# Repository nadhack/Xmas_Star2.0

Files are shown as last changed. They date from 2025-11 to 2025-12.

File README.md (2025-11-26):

Design files and documentation for the NADHack Xmas Star V2.0 as used in 
the SMD soldering workshop 2025.

* Addons - Addon files, source  and reference designs to enhance your stars.
* Docs - Assembly documentation greated using [MkDocs](https://www.mkdocs.org/)
* Hardware - [KiCad](https://www.kicad.org/) design files.

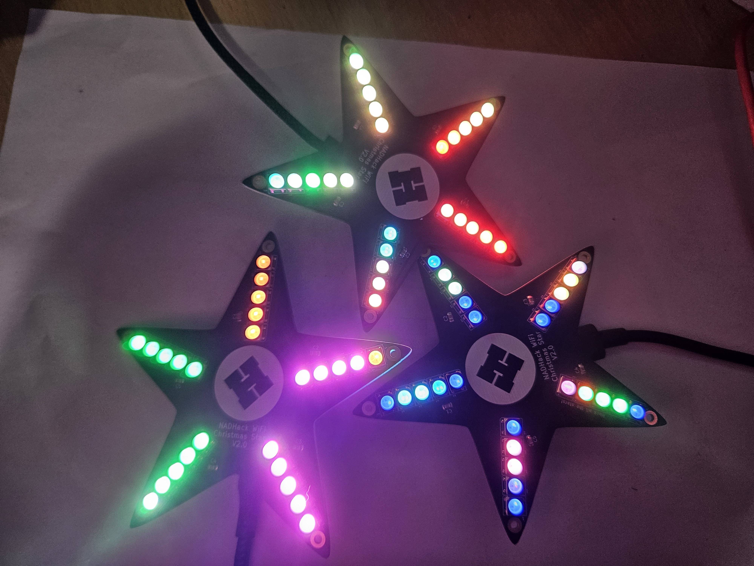
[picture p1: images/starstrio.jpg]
Trio of stars


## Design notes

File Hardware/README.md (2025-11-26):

Hardware files for the NADHack Xmas Star V2.0.

* ESP32_Xmas_Star_Module - [KiCad](https://www.kicad.org/) design files.
* Jigs - Source and 3D print files for holding star PCB while applying solderpaste.

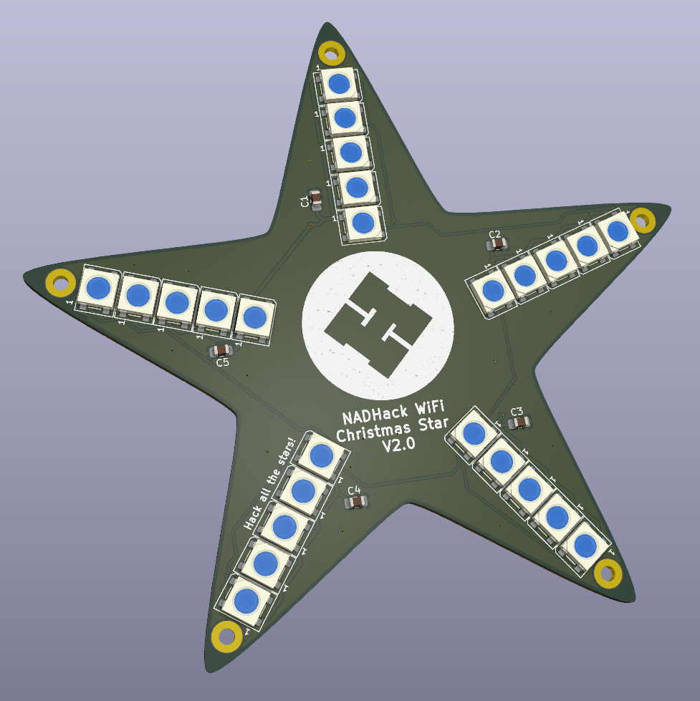
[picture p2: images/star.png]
rear


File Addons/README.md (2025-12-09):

Addon files for the NADHack Xmas Star V2.0.

These can be used as a starting point for your own projects. Source and usable files are available.

The main file is *staroutline.svg* which was used to create the star PCB outline. This can be used to get the correct shape.

Other files:

* *StarCover* Diffuser cover for star created with [OpenSCAD](https://openscad.org/). Source file and *.stl* file suitable for 3D printing.
* *StarBracket* Bracket for star, example is a tree topper created with [OpenSCAD](https://openscad.org/). Source file and *.stl* file suitable for 3D printing.
* *Seasonal_Star* for those that want a desk stand, Fusion360 and *.stl* file suitable for 3D printing. Designed and kindly shared by Craig Hogan.

Star cover/diffuser
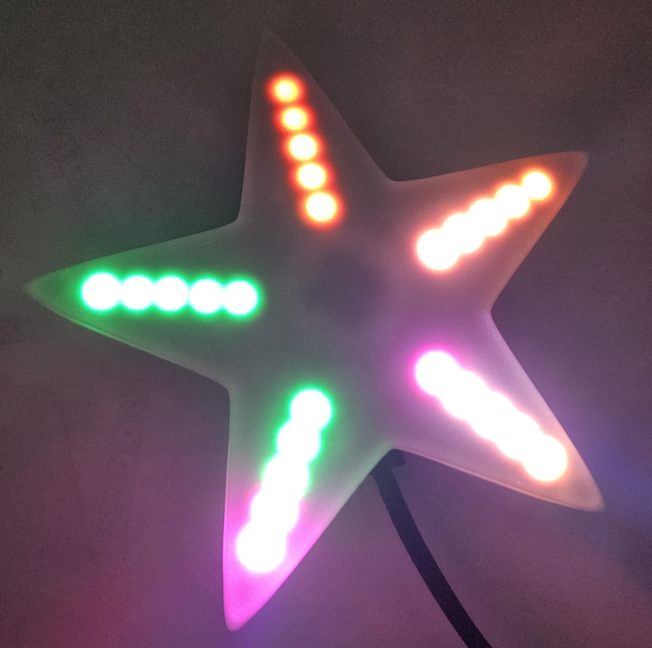
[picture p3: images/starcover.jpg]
starcover


Tree Topper bracket
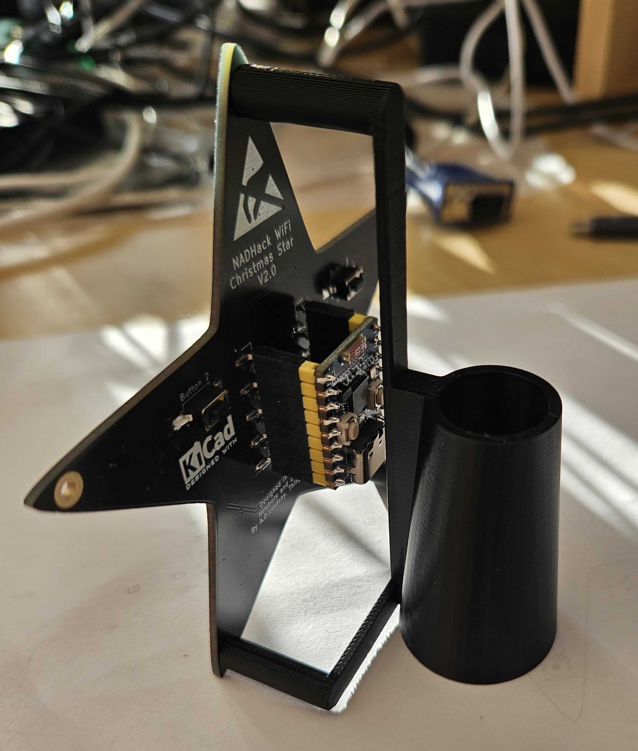
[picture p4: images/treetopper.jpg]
treetopper


Star Stick - Designed and kindly shared by Craig Hogan

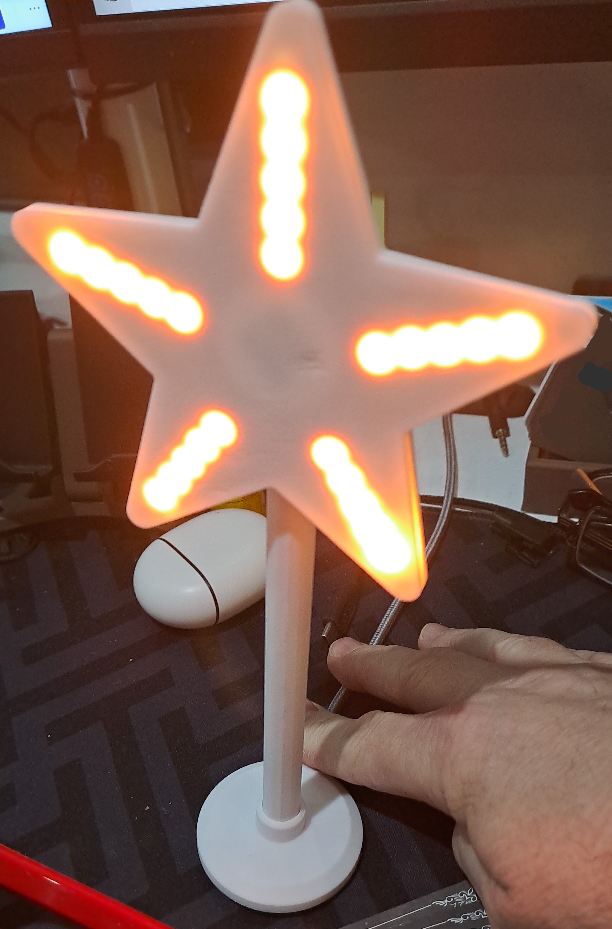
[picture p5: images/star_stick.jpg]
starstick


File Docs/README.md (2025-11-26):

Assembly documentation created using [MkDoc](https://www.mkdocs.org/)

Folders:

* docs - the source files
* site - the built files for uploading to a webserver. Currently viewable at [https://star.thingdevices.uk](https://star.thingdevices.uk)

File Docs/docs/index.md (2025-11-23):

# NADHack Introduction to Surface Mount Soldering workshop 2025

Welcome to the NADHack Introduction to Surface Mount Soldering workshop 2025!

Workshop aims:

* Show you the basic process for assembling a project using SMD components
* You try the process yourself to assemble a project
* Take home a working fully programmable, addressable LED star based on the ESP32-C3 Zero module.

# The NADHack Xmas Star V2.0

Has the following features:

* ESP32-C3 module with WiFi and Bluetooth.
* 25 individually addressable RGB LEDs.
* Programmable using Arduino IDE or can use ready made firmware such as WLED, which we will use.
* WLED includes an App to controll the star.
* Cool star shape with mounting and hanging holes.

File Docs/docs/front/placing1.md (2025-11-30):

# Front component Placement

The components should be identified, 5 capacitors and 25 addressable LEDs.

Working on one point of the star at a time, arrange 5 LEDs in the correct order, noting the position of the triangular cutout. This indicates pin 3, not the usual pin 1. Each point is placed identically.
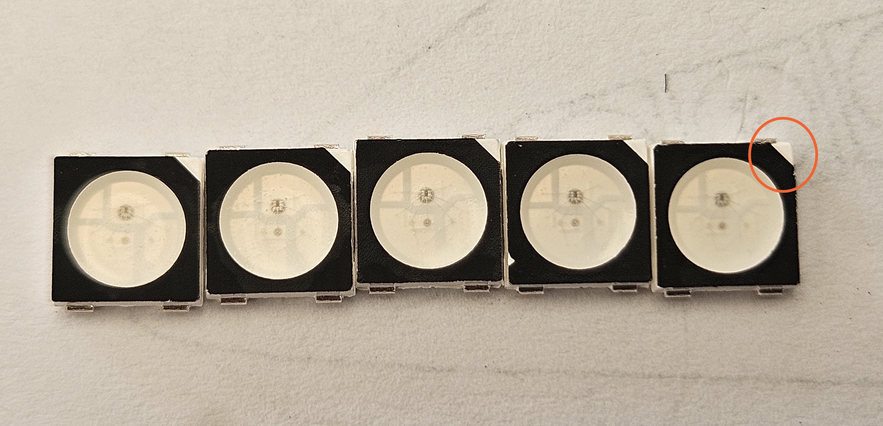
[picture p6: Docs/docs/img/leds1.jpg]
Placing LEDs


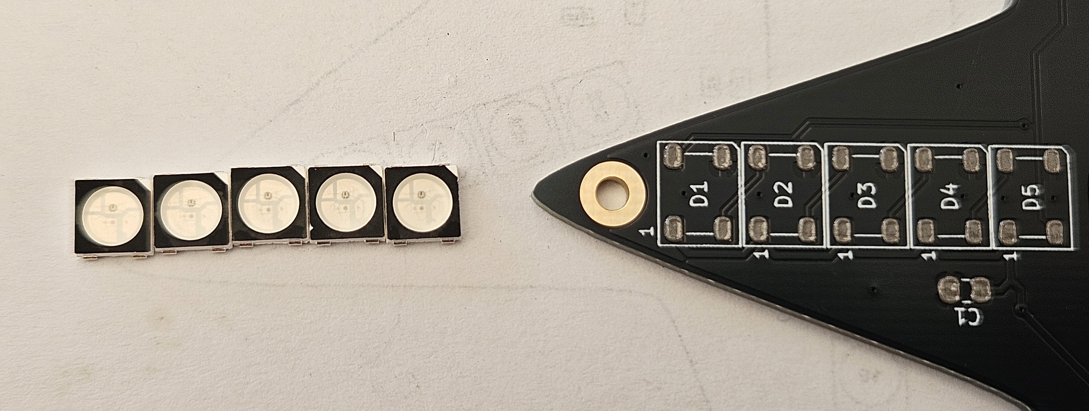
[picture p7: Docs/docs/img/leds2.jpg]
Placing LEDs


Using tweezers, place one of the capacitors onto the pads, use a coctail stick to hold the component down while removing the tweezers just incase it sticks and lifts away.
Place the first LED on the pads closest to the centre of the star, taking care not to have any clothing, jewellery or body parts touch the rest of the PCB as this could rub away the solderpaste. 
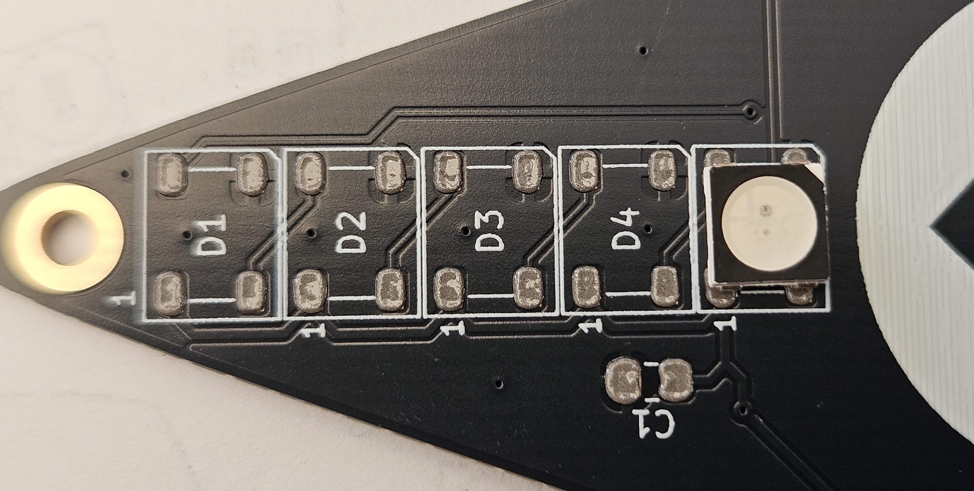
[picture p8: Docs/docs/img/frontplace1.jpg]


Line up 5 LEDs, orientated correctly and place one at a time on each star point.
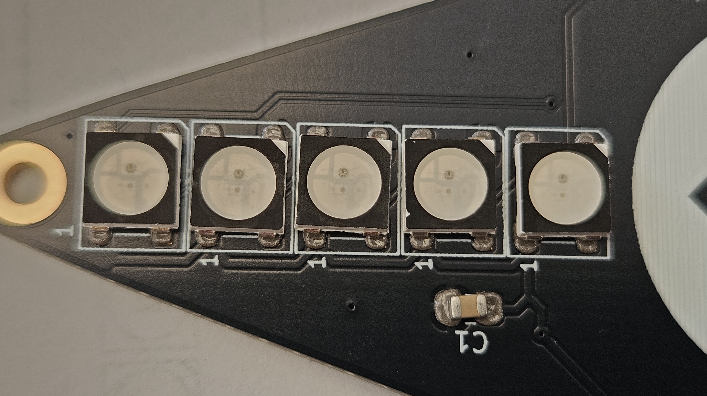
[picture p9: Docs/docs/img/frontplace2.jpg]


The board should look like this
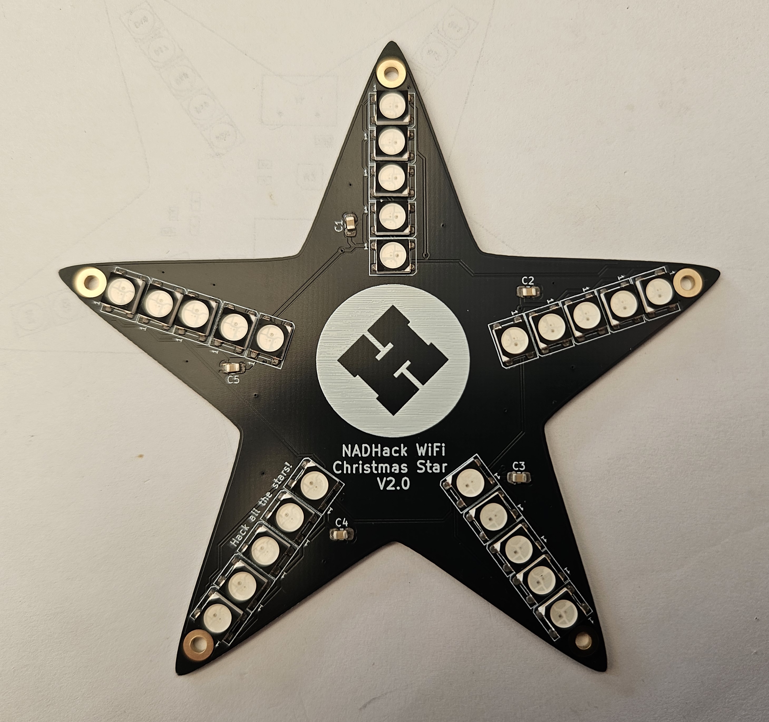
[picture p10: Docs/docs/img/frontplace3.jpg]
End result


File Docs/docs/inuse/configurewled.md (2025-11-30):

# Configuring WLED

On the ESD bag containing the ESP32 module there is a label with the Access Point (AP) configured on this ESP32 module. Look for the *WLED-AP-xxxxxx* access point using your phone or laptop WiFi and connect to it. The screenshots below are from using a phone to configure the star.
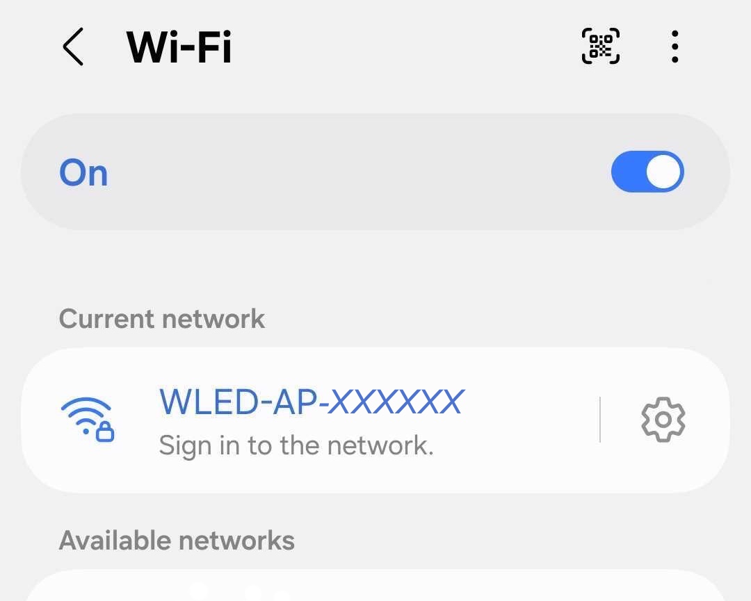
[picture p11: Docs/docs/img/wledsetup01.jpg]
Setup


Click on the correct *WLED-AP-xxxxxx* to connect to it then click on *Sign in to the network* which takes you to the ESP32 WLED configuration. If a password is required then enter *wled1234*.
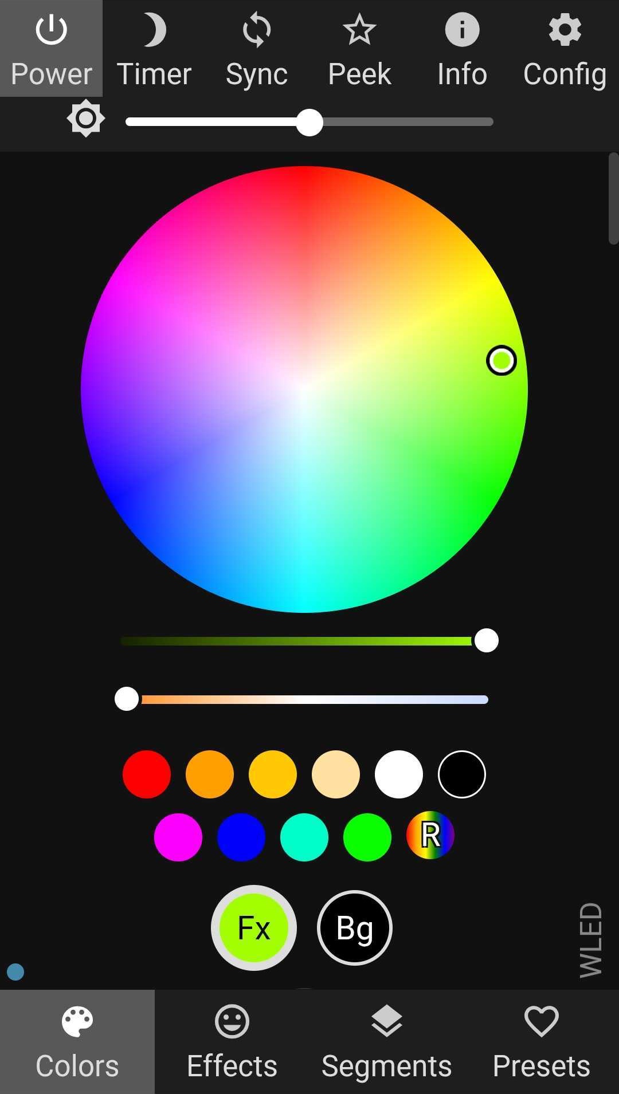
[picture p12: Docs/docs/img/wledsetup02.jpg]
Setup


Click on the *Config* button then the *WiFi Setup* button.
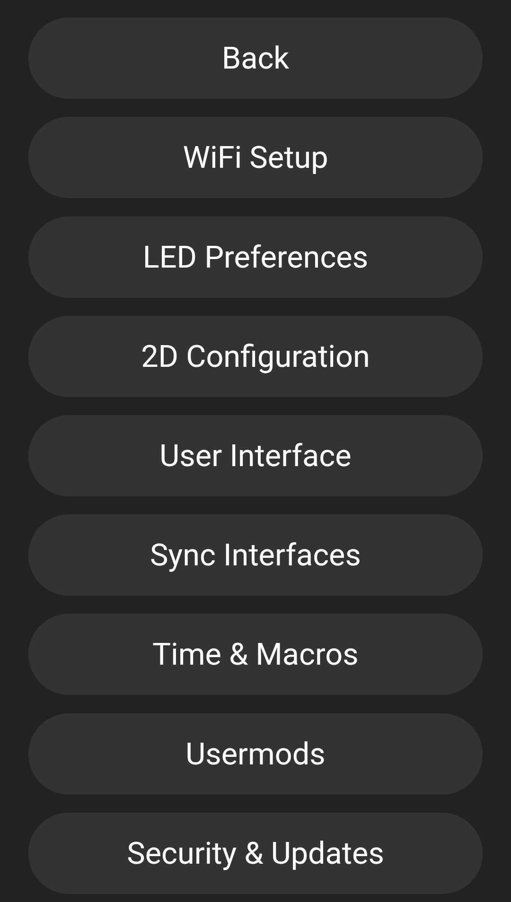
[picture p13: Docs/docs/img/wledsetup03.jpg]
Setup


Enter your WiFi network settings.
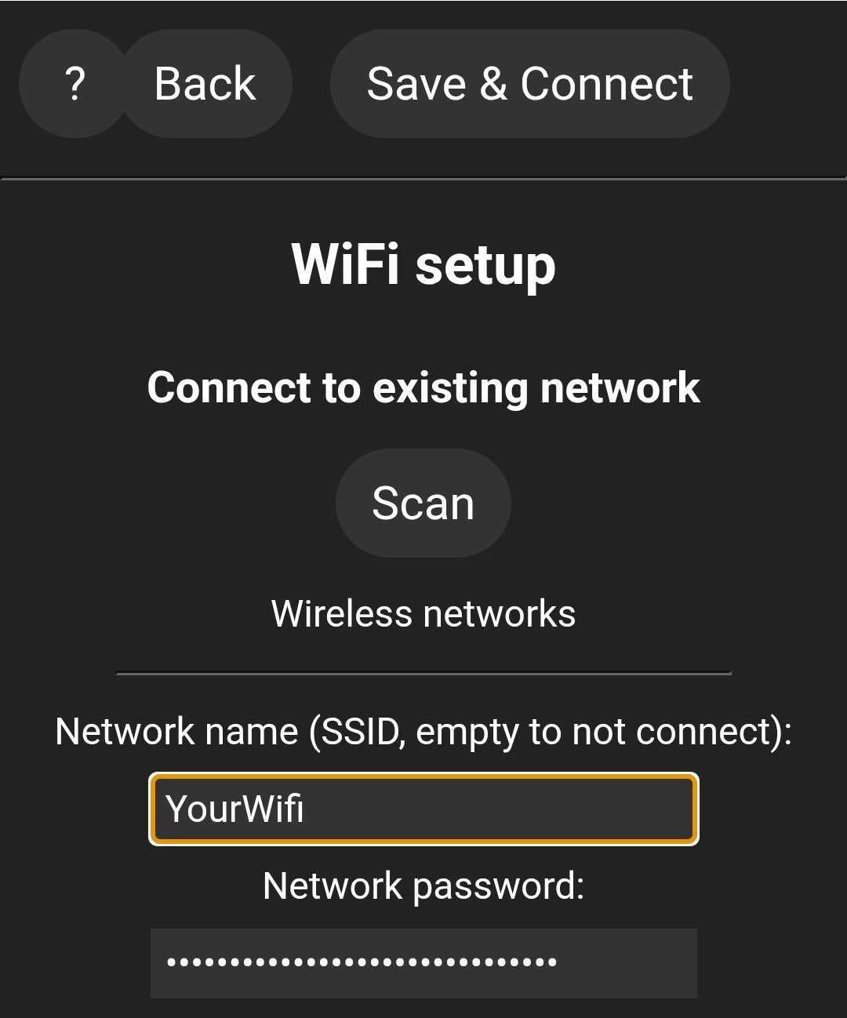
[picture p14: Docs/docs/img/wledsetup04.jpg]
Setup


The app will disconnnect from the star and reconnect to your previously connected WiFi.

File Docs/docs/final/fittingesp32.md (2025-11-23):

# Installing the ESP32 module

Insert the ESP32 module into the header sockets, ensure the USB-C socket is at the correct end, pointing downwards towards the text USB-C.

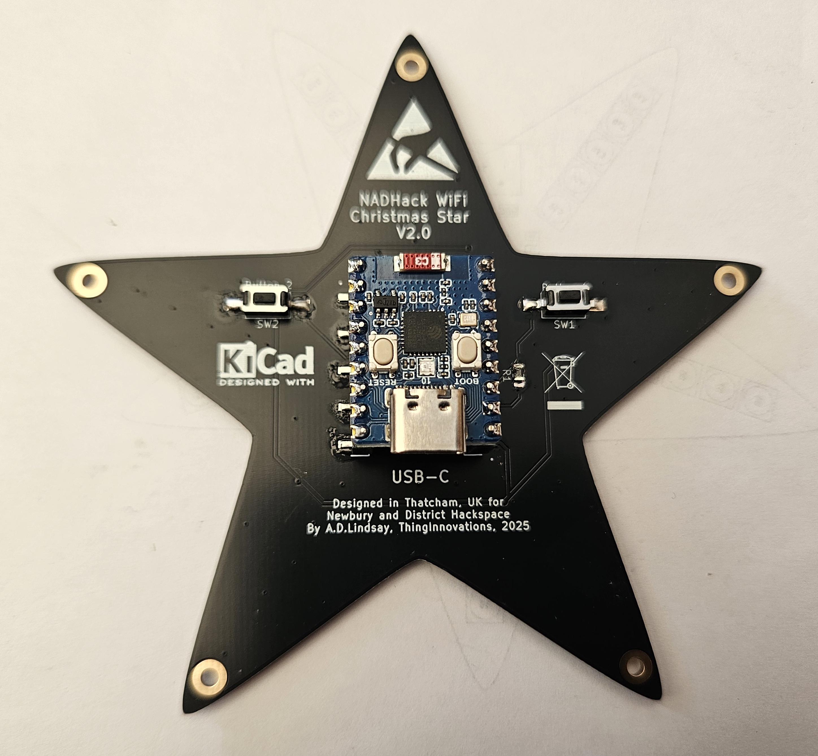
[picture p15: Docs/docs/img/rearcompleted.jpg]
Install ESP32


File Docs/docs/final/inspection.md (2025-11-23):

# Inspection

Before installing the ESP32 module, visually check the solder joints on both the front and rear of the PCB.

Look for:

* Solder bridges between pads.
* Pads not soldered properly.

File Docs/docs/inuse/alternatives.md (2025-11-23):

# Alternatives

As an alternative to using WLED, the ESP32 on the star can be programmed directly using the Arduino IDE. The scope for this is beyond the contents of this workshop.

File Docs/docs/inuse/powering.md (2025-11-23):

# Powering Star

The Xmas Star 2.0 includes a USB-C connector for programming and power. This can be connected to a laptop, USB mains adaptor or a powerbank.

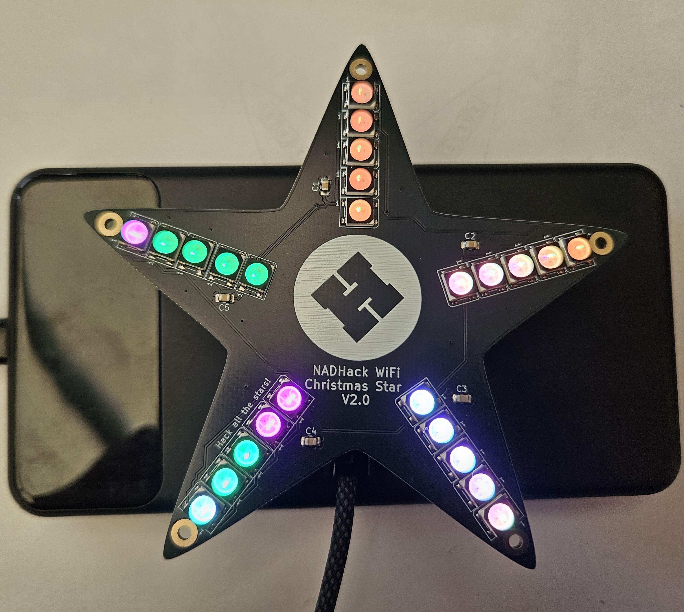
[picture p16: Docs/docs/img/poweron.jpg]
Powering


If you see all the LEDs light up and produce a pattern then congratulations, you have completed the hard part of the workshop.

If your star fails to power up and show a pattern, don't worry, there may be a faulty solder joint. One of the helpers will be able to help and fix it for you.

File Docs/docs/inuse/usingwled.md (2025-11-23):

# Using WLED

Run the *WLED App* and your star should show up. The slider controls the brightnes and the toggle powers the LEDs on and off. Click on the name to enter the configuration screens.
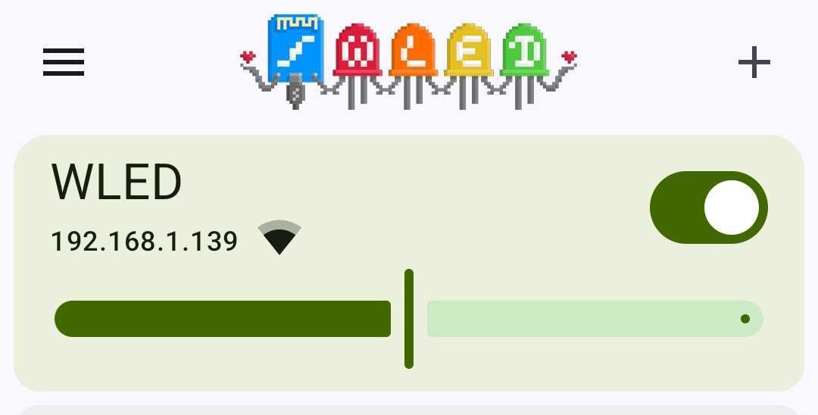
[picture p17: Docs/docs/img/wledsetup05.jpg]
Setup


From the *Config* button, select *LED Preferences* to verify the correct LED setup. It should be set to *WS281x*, Length of *25* and the GPIO set to *2* as shown here.
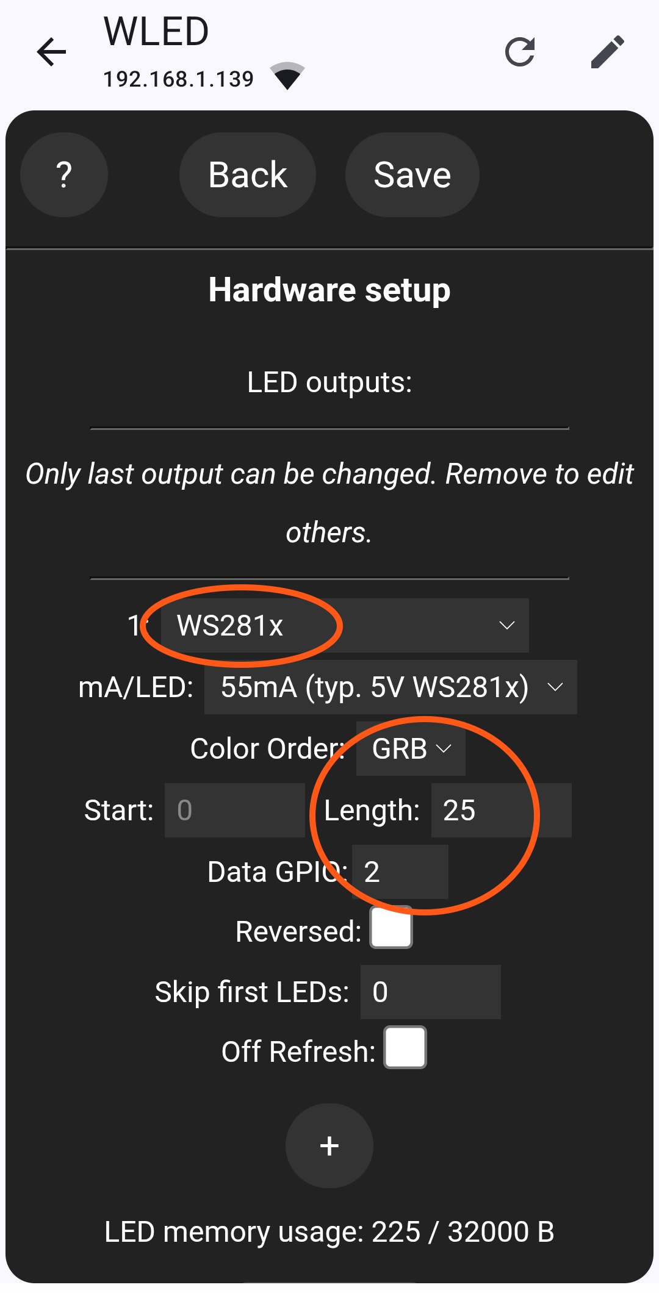
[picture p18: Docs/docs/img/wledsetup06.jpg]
Setup


Selecting the *Effects* button at the bottom brings up a list of effects that can be selected. Some work well with the star, others are more suited to other LED configurations such as LED matrix. 
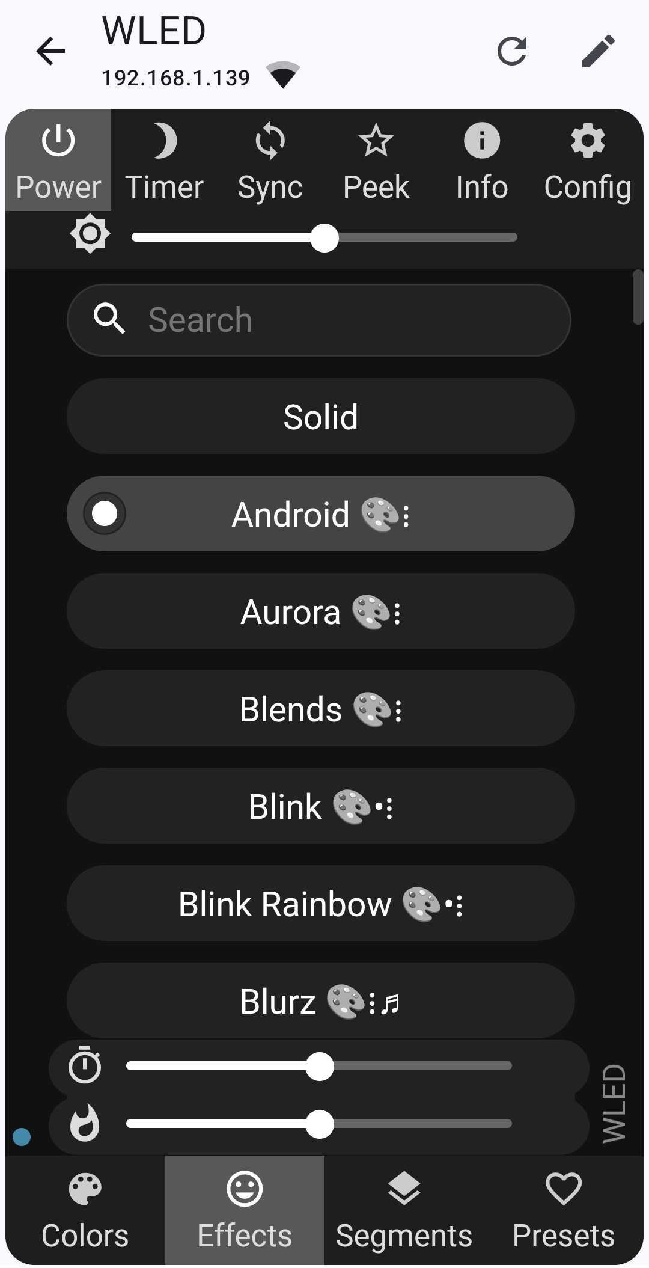
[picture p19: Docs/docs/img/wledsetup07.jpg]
Setup


Selecting the *Colors* (US Spelling!!) button takes to toy a screen where different colour sets can be selected. 
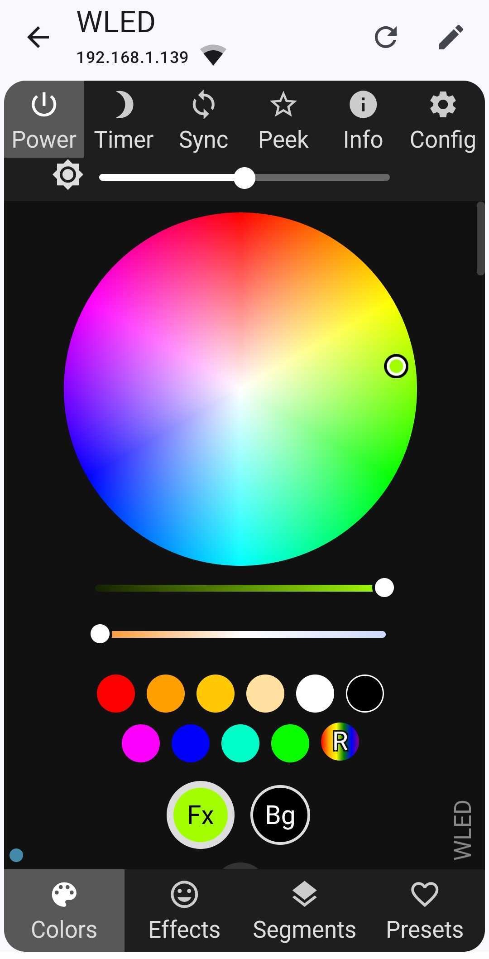
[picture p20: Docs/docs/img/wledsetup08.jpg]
Setup


Once you are happy with an effect and want to keep it, select the *Presets* button at the bottom. If you select the *Apply at boot* then the effect will be shown when your star is powered on without having to use the app to set the colours and effect.
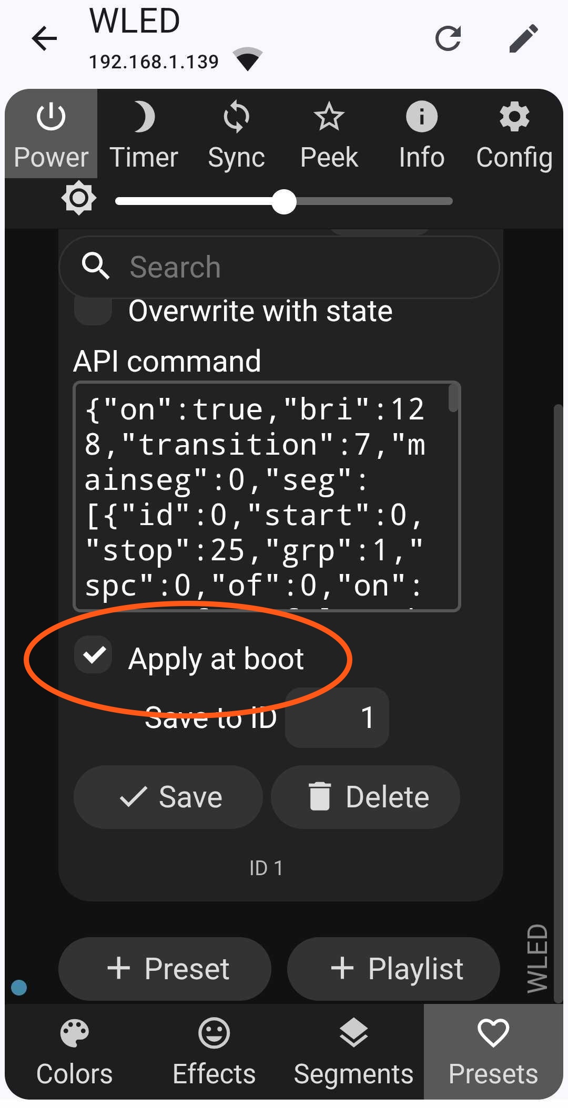
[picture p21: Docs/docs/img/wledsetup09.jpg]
Setup


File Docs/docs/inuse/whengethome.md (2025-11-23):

# When you get home

The first thing to do is to reset the WiFi settings to reconfigure it for your own WiFi.

With the star powered on, hold down the right hand button labelled *SW1* then press and release the *RESET* button. Keep pressing *SW1* for about 10 seconds.

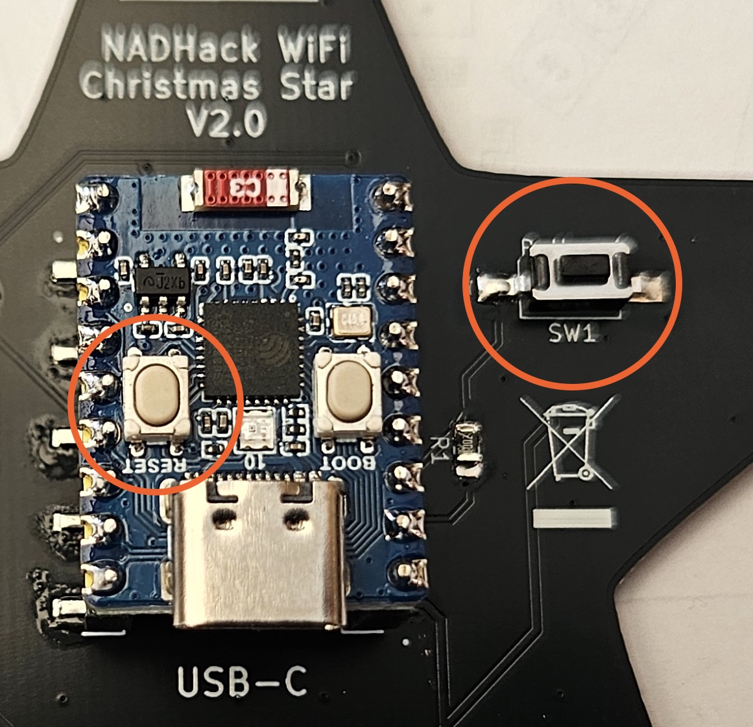
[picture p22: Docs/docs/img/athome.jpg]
reset


Proceed to the previous [setup instructions](configurewled.md)

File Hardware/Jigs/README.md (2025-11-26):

Hardware files for the NADHack Xmas Star V2.0.

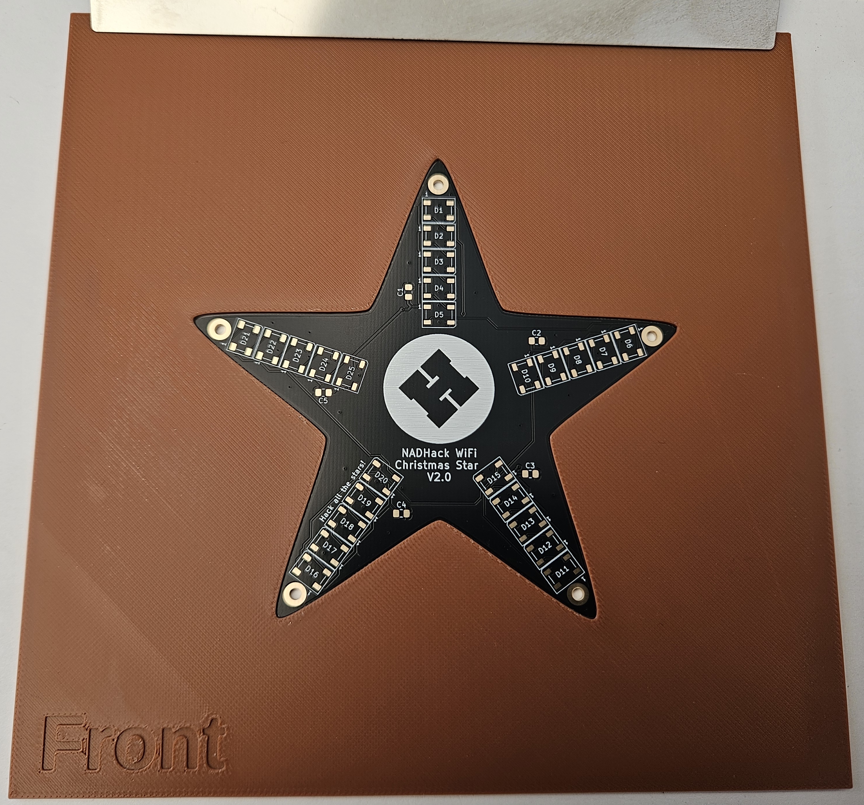
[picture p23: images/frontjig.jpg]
front


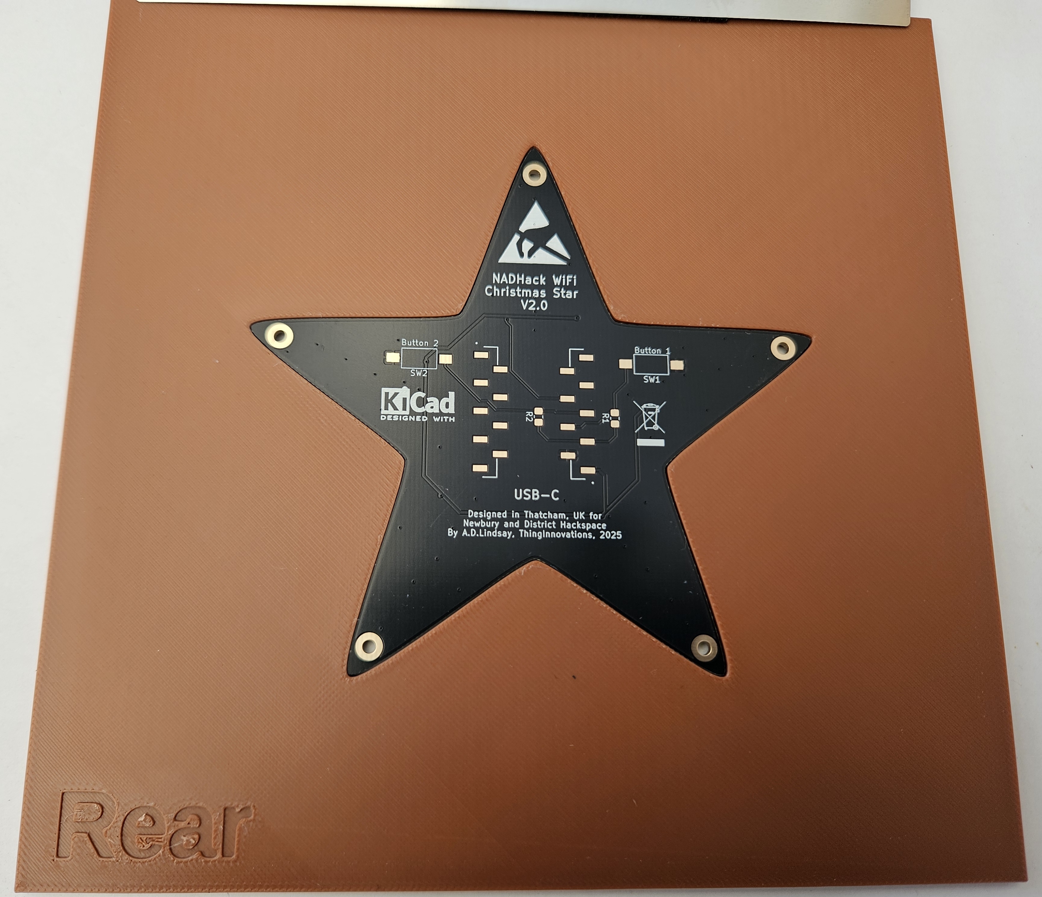
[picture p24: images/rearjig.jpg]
rear


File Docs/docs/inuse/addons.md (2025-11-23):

# Addons

The Xmas Star 2.0 files are all available on the [Github repository](https://github.com/nadhack/Xmas_Star2.0).

The idea is that you have the files you need to create your own addons and new versions. The original star shape outline is available in the file *staroutline.svg*

# 3D printed cover

A simple star shaped diffusing cover created using [OpenSCAD](https://openscad.org/), the script uses the *staroutline.svg* file.
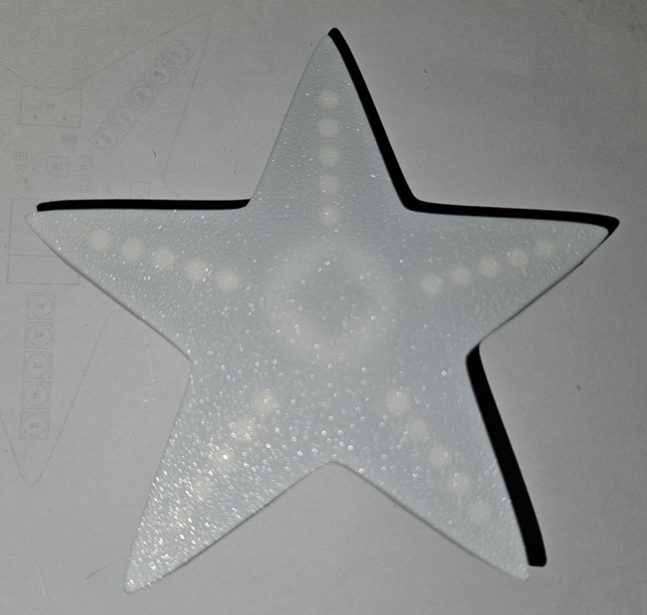
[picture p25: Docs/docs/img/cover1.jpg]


addons

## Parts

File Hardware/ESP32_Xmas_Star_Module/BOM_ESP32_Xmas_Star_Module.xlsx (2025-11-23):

Reference | Qty | Value | DNP | Footprint | Datasheet | Digi-Key Order | PiHut | Unit Cost | Line Cost
C1,C2,C3,C4,C5 | 5 | 100nF |  | Capacitor_SMD:C_0805_2012Metric_Pad1.18x1.45mm_HandSolder | ~ | 1276-1003-1-ND |  | 0.06 | 0.3
D1,D2,D3,D4,D5,D6,D7,D8,D9,D10,D11,D12,D13,D14,D15,D16,D17,D18,D19,D20,D21,D22,D23,D24,D25 | 25 | WS2812B |  | LED_SMD:LED_WS2812B_PLCC4_5.0x5.0mm_P3.2mm | https://cdn-shop.adafruit.com/datasheets/WS2812B.pdf |  |  | 0.03 | 0.75
J1,J2 | 2 | SSW-109-22-X-S-VS |  | SSW-109-22-F-S-VS:SAMTEC_SSW-109-22-X-S-VS |  | SSW-109-22-F-S-VS-ND |  | 1.57 | 3.14
R1,R2 | 2 | 10K |  | Resistor_SMD:R_0805_2012Metric_Pad1.20x1.40mm_HandSolder | ~ | RMCF0805FT10K0CT-ND |  | 0.08 | 0.16
SW1,SW2 | 2 | SW |  | SWITCH TACTILE SPST-NO 0.05A 12V |  | 108-GSPTS004003CT-ND |  | 0.15 | 0.3
M1 | 1 | ESP32-C3-Mini |  | Waveshare ESP32-C3 Zero Mini Development Board | https://www.waveshare.com/wiki/ESP32-C3-Zero |  | WAV-25532 | 4.4 | 4.4
PCB | 1 |  |  | ESP32_XmasStarModV2 |  |  |  | 3.2 | 3.2
 |  |  |  |  |  |  |  |  | 12.25

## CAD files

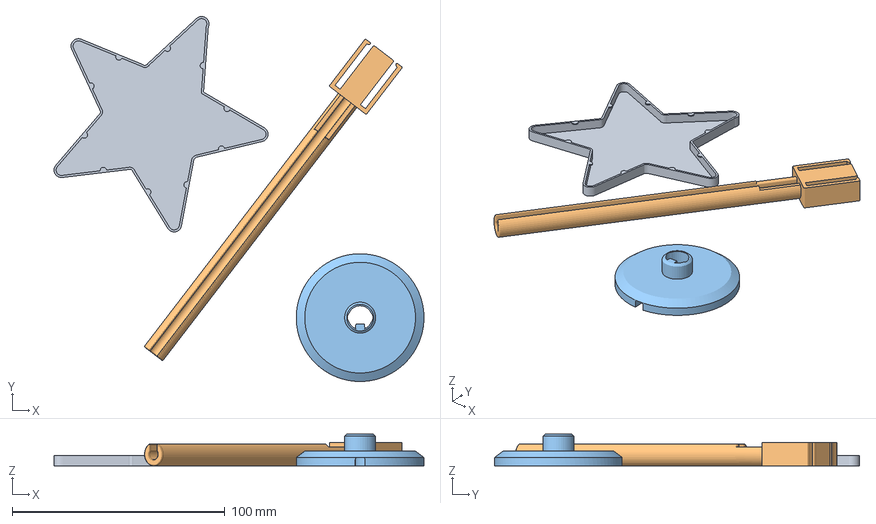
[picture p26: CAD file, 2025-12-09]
Addons/Seasonal_Star.3mf
173.8 x 171.4 x 15.0 mm
seasonal star stick v3.stl_1
seasonal star stick v3.stl_2
seasonal star stick v3.stl_3

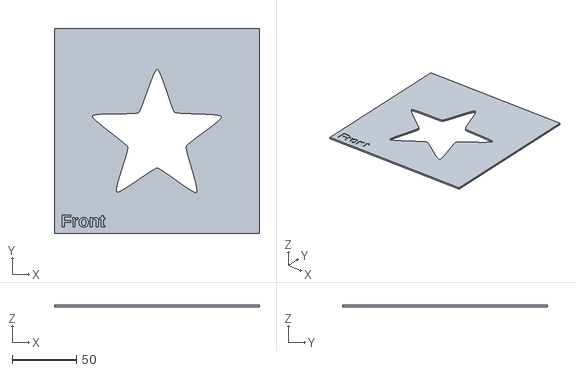
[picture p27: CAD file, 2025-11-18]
Hardware/Jigs/FrontPaste.stl
160.0 x 160.0 x 1.60

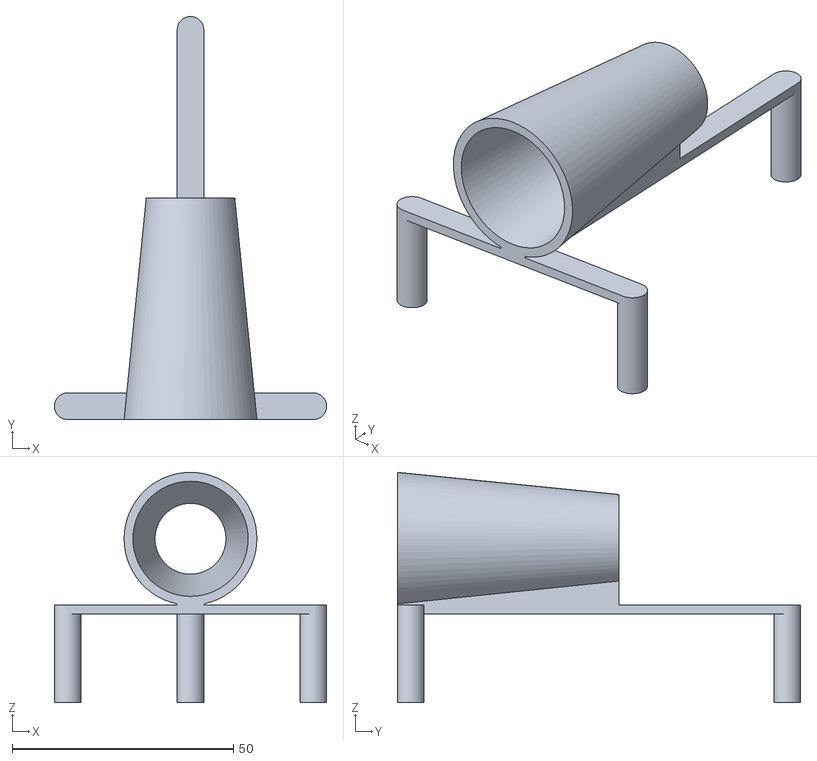
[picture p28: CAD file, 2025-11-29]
Addons/StarBracket.stl
61.5 x 91.0 x 52.0

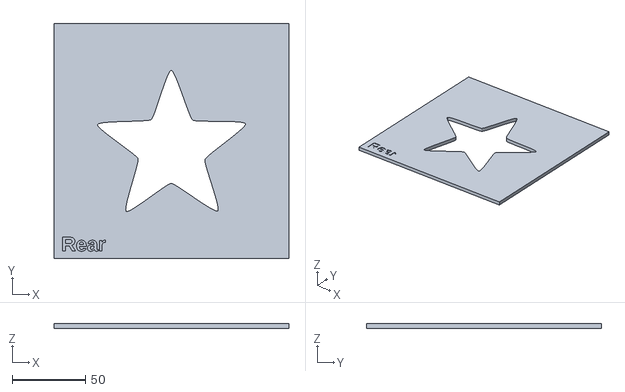
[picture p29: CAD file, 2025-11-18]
Hardware/Jigs/RearPasteJig.stl
160.0 x 160.0 x 3.20

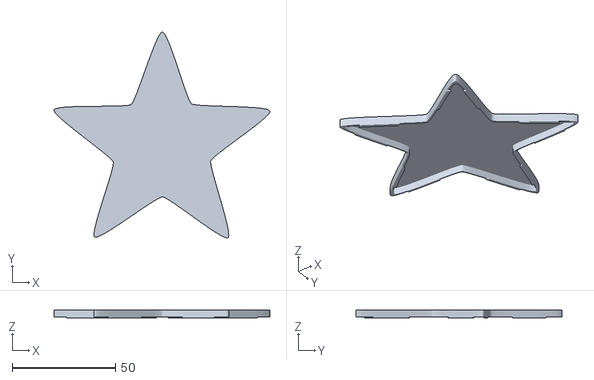
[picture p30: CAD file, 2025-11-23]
Addons/StarCover.stl
104.8 x 99.9 x 4.00

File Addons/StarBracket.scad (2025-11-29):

// Star tree topper adaptor
// Use M2 x 8mm screws to secure 

$fn=60;

// 8 for below ESP32 module, 22 for above
$frameHeight=22;
$frameThickness=2;

// Part that slips over tree top point
module treeHolder() {
    rotate([-90,0,0]) 
    difference() {
        union() {
            cylinder(h=50,d1=30,d2=20,center=false);
            translate([-3,1,0]) cube([6,15,50]);
        }
        cylinder(h=50,d1=26,d2=16,center=false);
    }
}

// Tower with screw holes
module screwTower() {
    difference() {
        cylinder(h=$frameHeight,d=6,center=false);
        cylinder(h=8,d=2,center=false);
    }
}

// T-shaped frame to screw onto star
module starFrame() {
    screwTower();
    translate([55.5,0,0]) screwTower();
    translate([27.75,85,0]) screwTower();
    translate([0,-3,$frameHeight-$frameThickness]) cube([55.5,6,2]);
    translate([24.75,0,$frameHeight-$frameThickness]) cube([6,85,2]);
}

// Put it all together
module treeTopper() {
 translate([27.75,-3,$frameHeight+15]) treeHolder();
    starFrame();
}


treeTopper();

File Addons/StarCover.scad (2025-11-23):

// Cover for xmas star pcb

module outerCircle() {
    difference() {
        cylinder(h=0.5,d=115,center=true);
        cylinder(h=0.5,d=90,center=true);
    }
}

module innerCircle() {
    cylinder(h=0.5,d=65,center=true);
}

module outer() {
    scale([1.05,1.05,1]) linear_extrude(height = 4.0) import(file="staroutline.svg",center=true);
}

module inner() {
    translate([0,0,0.5]) scale([1.01,1.01,1]) linear_extrude(height = 3.0) import(file="staroutline.svg",center=true);

//    difference() {
        #scale([0.98,0.98,1]) linear_extrude(height = 0.5)
            import(file="staroutline.svg",center=true);
        translate([0,-5,0.250]) outerCircle();
        translate([0,-5,0.250]) innerCircle();
//    }
}

module cover() {
    difference() {
        outer();
        inner();
        translate([0,-5,0.250]) outerCircle();
        translate([0,-5,0.250]) innerCircle();    }
}


cover();

//inner();

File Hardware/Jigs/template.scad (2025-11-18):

// template for xmas star pcb

module front() {
    difference() {
        cube([160,160,1.6]);
        translate([80,80,0]) 
        scale([1.01,1.01,1]) linear_extrude(height = 1.6) import(file="staroutline.svg",center=true);
        translate([5, 5, 1.20]) 
            linear_extrude(height = 0.5) {
                text("Front", font = "Liberation Sans:style=Bold");
            }
    }
}

// The back template, needs to be thicker and flipped over
module back() {
    difference() {
    translate([160,0,0]) rotate([0,180,0])
    difference() {
        cube([160,160,3.2]);
        translate([80,80,0]) 
        scale([1.01,1.01,1]) linear_extrude(height = 3.2) import(file="staroutline.svg",center=true);
    }


        translate([5, 5, -.40]) 
            linear_extrude(height = 0.5) {
                text("Rear", font = "Liberation Sans:style=Bold");
            }
    }
}

front();
//back();

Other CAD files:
Addons/Seasonal_Star.f3d
Addons/Seasonal_Star.stl

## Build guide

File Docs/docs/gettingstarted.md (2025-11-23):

# Getting Started

The Kit includes all the parts needed to build your star.
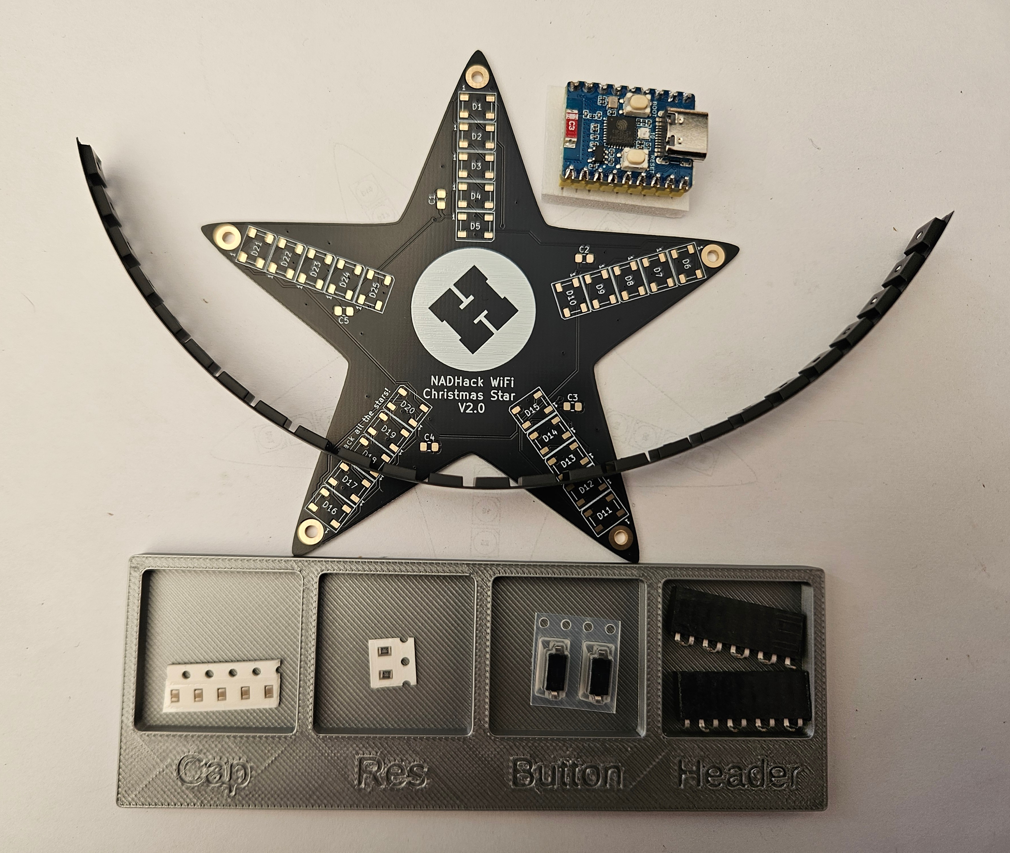
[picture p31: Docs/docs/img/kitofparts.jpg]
kit


For easy of assembly, a custom made tray has been provided to hold the components except the strip of LEDs.
Identify the components and place into the sections in the tray, the components in the strips can be removed.
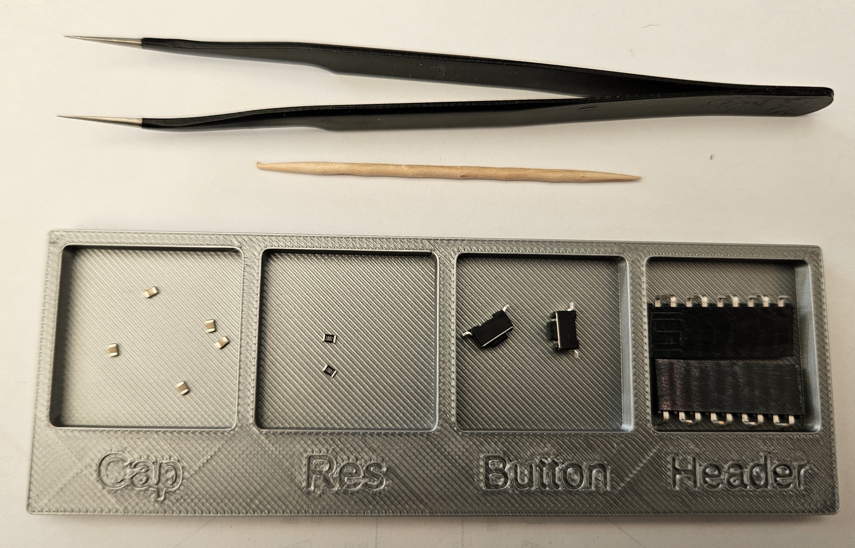
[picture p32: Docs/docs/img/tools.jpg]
tools


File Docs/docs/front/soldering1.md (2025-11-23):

# Front Soldering

The PCB can now be soldered using either a reflow oven or a hot plate. The reflow oven used here is basically a modified toaster oven with a controller that is programmed to heat up using a generic timing profile.

Carefully place on the shelf without touching the components.
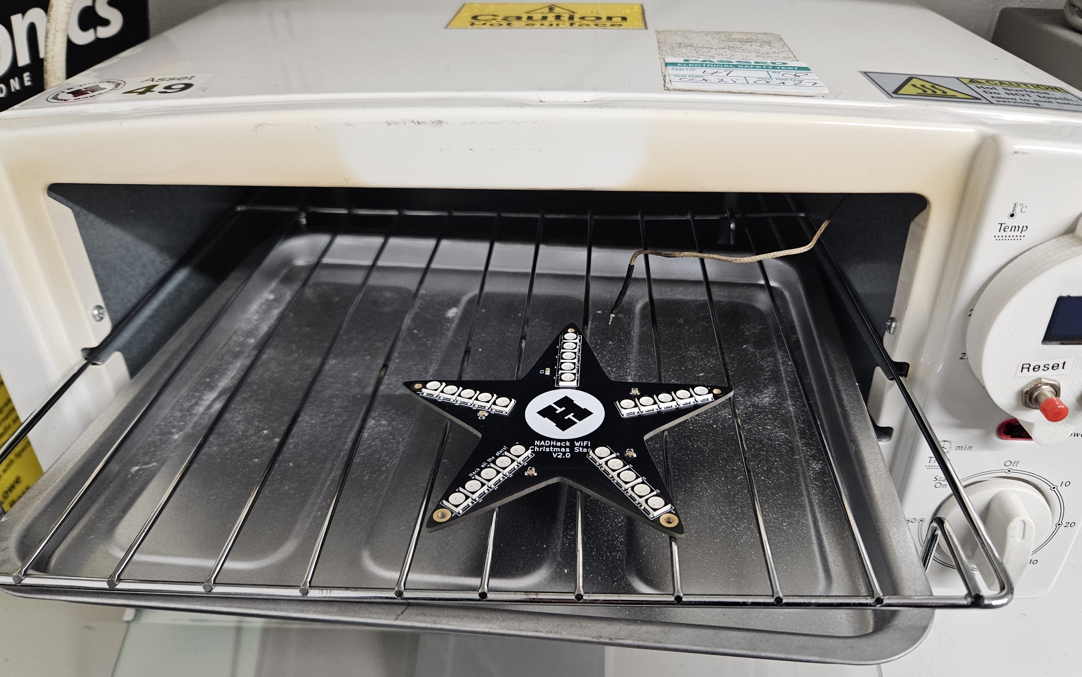
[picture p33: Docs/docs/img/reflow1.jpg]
Reflow Oven


Close the door.
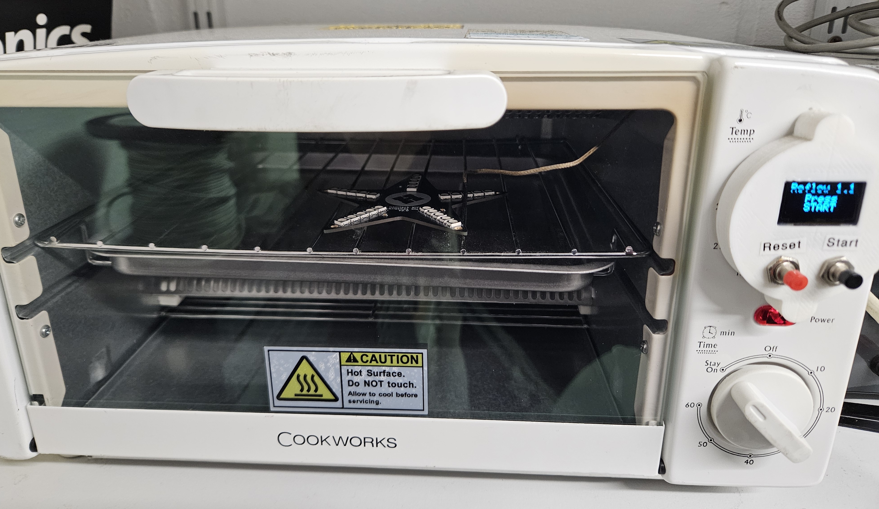
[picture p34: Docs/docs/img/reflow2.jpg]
Reflow Oven


Switch the oven on and Start the program. It is pre-programmed to heat up at a set rate so that the components heat up evenly.
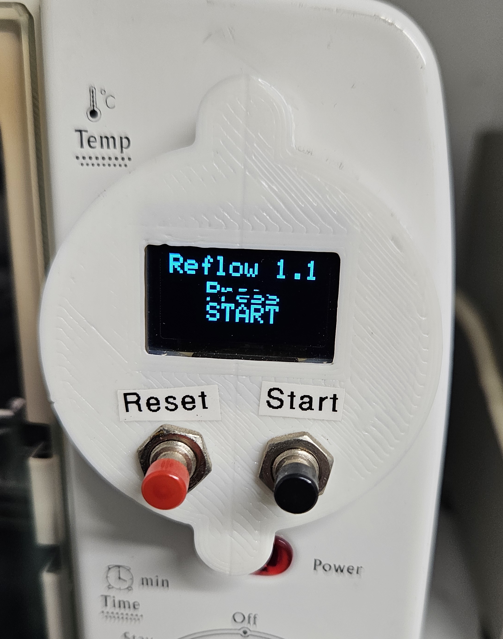
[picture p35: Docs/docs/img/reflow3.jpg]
Reflow Oven


When the cycle has finished open the door and allow the PCB to cool down before touching it. At this point the solder is still molten and any movement can dislodge the components.

An alternative to the reflow oven is a hotplate, however these have no control over temperature and timings. The hotplate here is too small to fully solder the star and it needs careful handling to ensure it can be fully soldered.
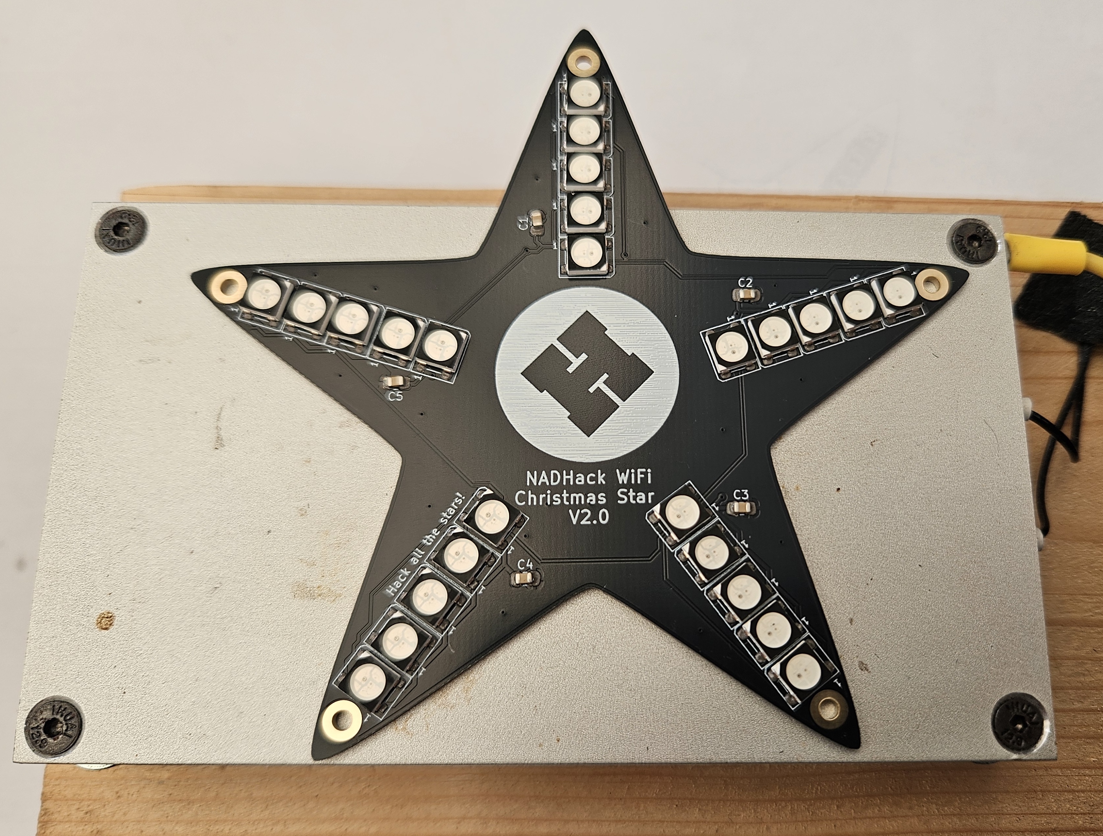
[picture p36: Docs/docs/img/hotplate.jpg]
Hot Plate


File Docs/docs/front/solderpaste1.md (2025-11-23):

# Front Solderpaste

Unlike traditional electronics assembly with through hole components, we need to use a solder paste which is made up of tiny balls of solder in a liquid flux to create a spreadable paste.

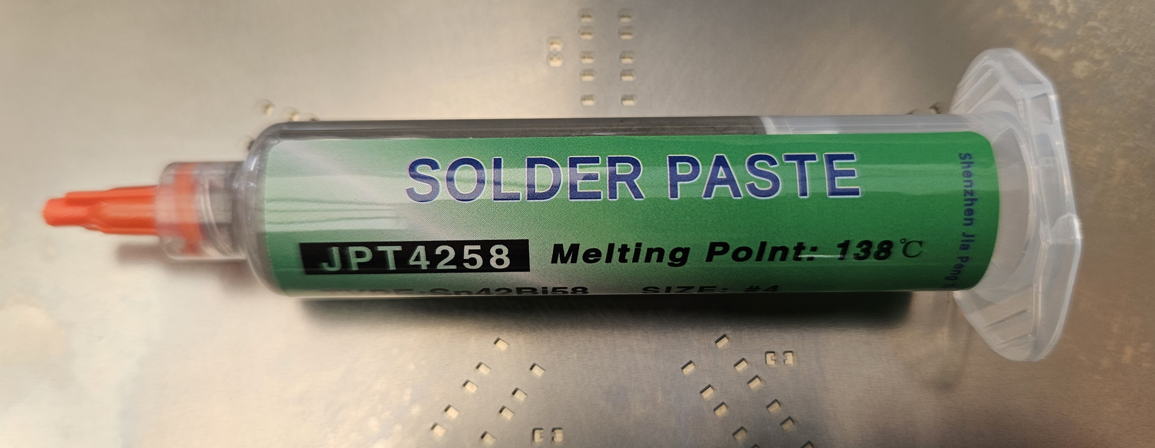
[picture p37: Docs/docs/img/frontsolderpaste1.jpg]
Solderpaste


A stainless steel stencil is used to ensure the solderpaste is applied to the component pads. These are normally ordered at the same time as the PCBs. The stencil thickness will determine how much paste is placed onto the pads.

The PCB is placed into the front holder, the stencil is placed over the top and a scraper is used to spread the paste across the holes using a single smooth motion.

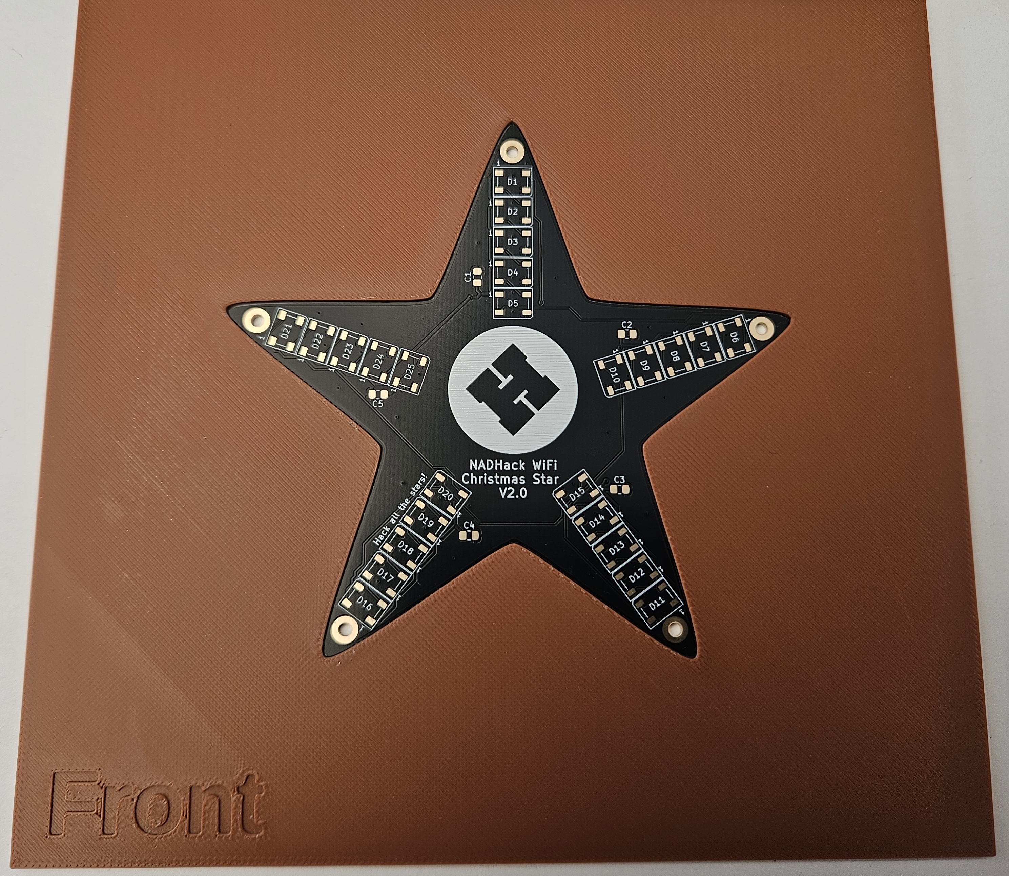
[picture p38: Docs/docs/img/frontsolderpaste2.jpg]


Apply stencil, ensure the pads are visible through the stencil holes. Squeeze out a blob of solderpaste as shown in the circled part.
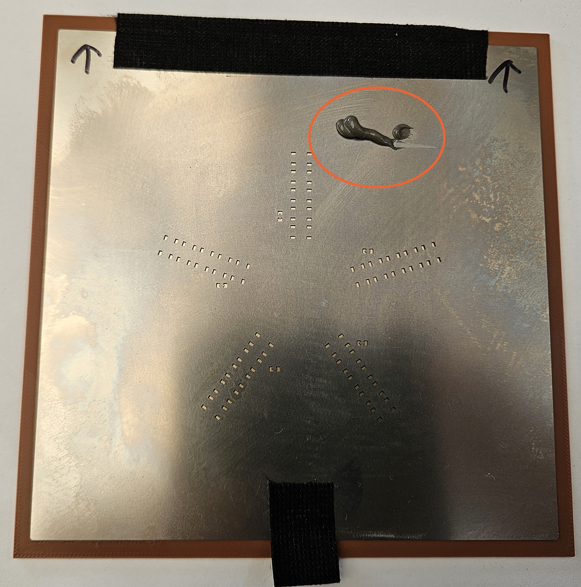
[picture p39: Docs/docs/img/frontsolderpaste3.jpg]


Apply the paste. It can be easier to apply to each star point in turn.
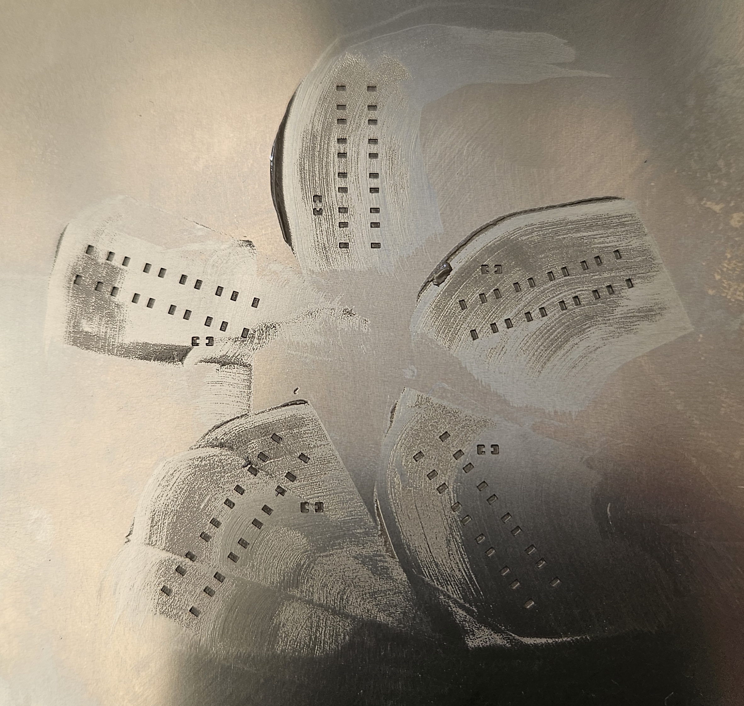
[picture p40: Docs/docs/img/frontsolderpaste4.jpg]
Paste


Carefuly lift up the stencil. The board should look like this.
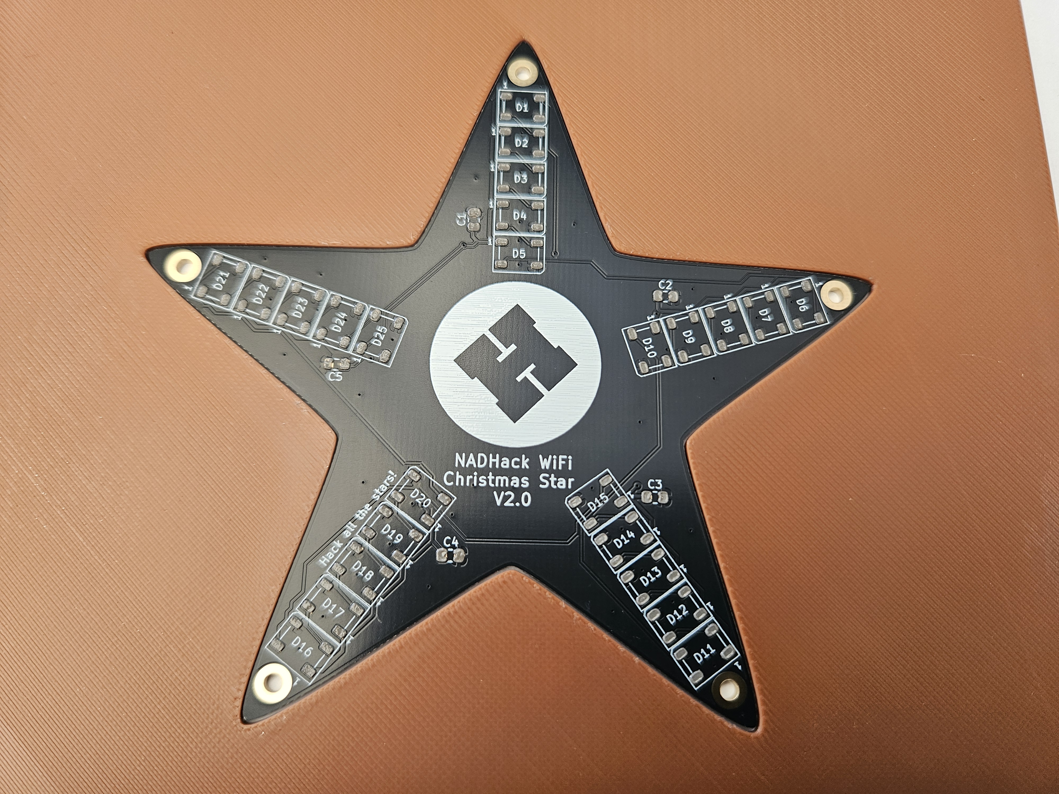
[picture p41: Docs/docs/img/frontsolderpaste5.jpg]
Paste


Close up of the pads.
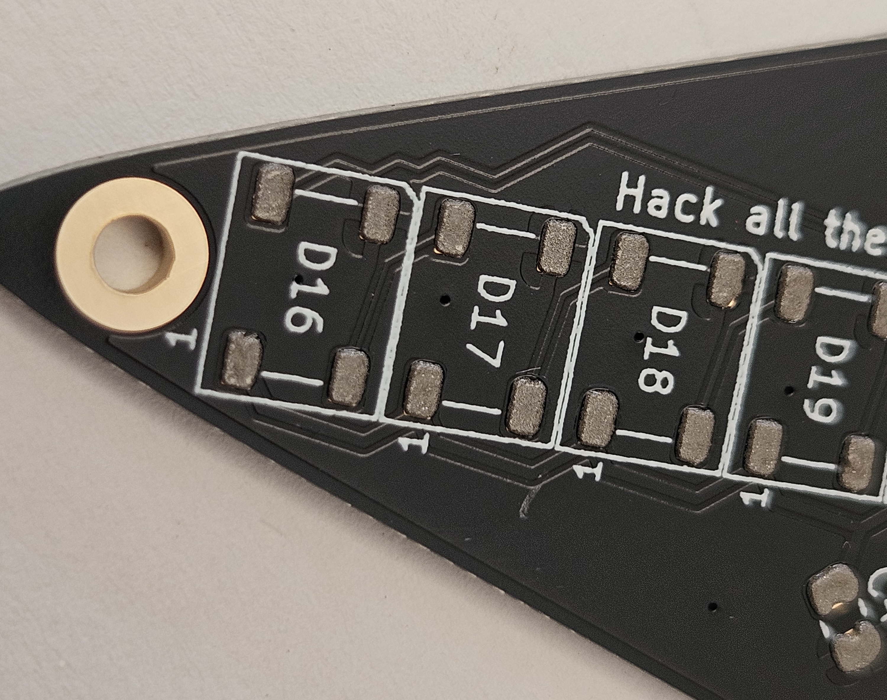
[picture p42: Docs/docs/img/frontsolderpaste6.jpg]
Paste


The stencil can be cleaned using IPA and a paper towel ready for the next person to use. Remember to clean both sides.

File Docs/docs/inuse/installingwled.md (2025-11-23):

# Installing WLED

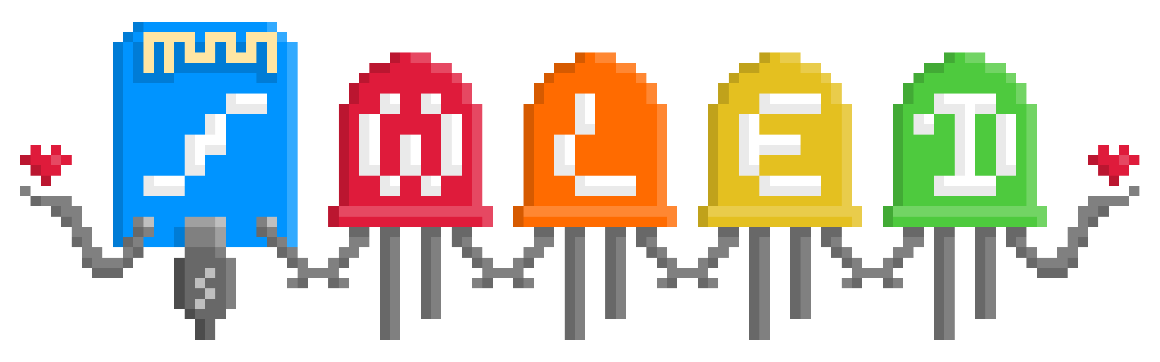
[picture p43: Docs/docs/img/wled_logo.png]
WLED Logo


The ESP32 modules supplied with the kits have the WLED firmware pre-installed so they are ready to go.

For completeness, the [WLED website](https://kno.wled.ge/) has a lot of information on setting up and using the software.

The easiest way to load the firmware to a new or existing device is to use the [WLED Web Installer](https://install.wled.me/)

# WLED App

The WLED Native app is available at:

* For [Android](https://play.google.com/store/apps/details?id=ca.cgagnier.wlednativeandroid)
* For [iOS](https://apps.apple.com/us/app/wled-native/id6446207239)

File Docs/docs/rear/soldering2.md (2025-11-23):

# Rear Soldering

The components on the rear side are to be soldered by hand using a regular soldering iron to melt the solderpaste.

For the first joint it is advisable to use a coctail stick to hold the component in place as there is a risk that when the soldering iron is removed it can take the component with it.

Solder the resistors and pushbuttons.
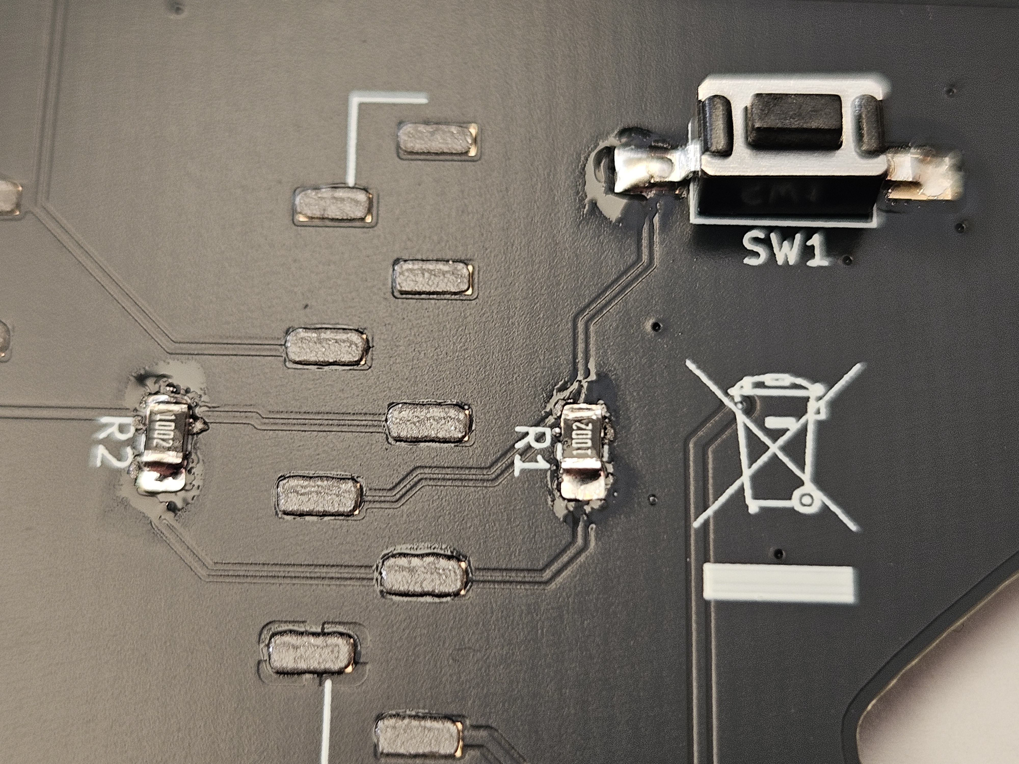
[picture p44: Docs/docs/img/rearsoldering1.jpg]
Hand solder


Push the 2 headers onto the ESP32 module, ensure the 5 legs are outside and 4 legs inside. This is to match the PCB pads.
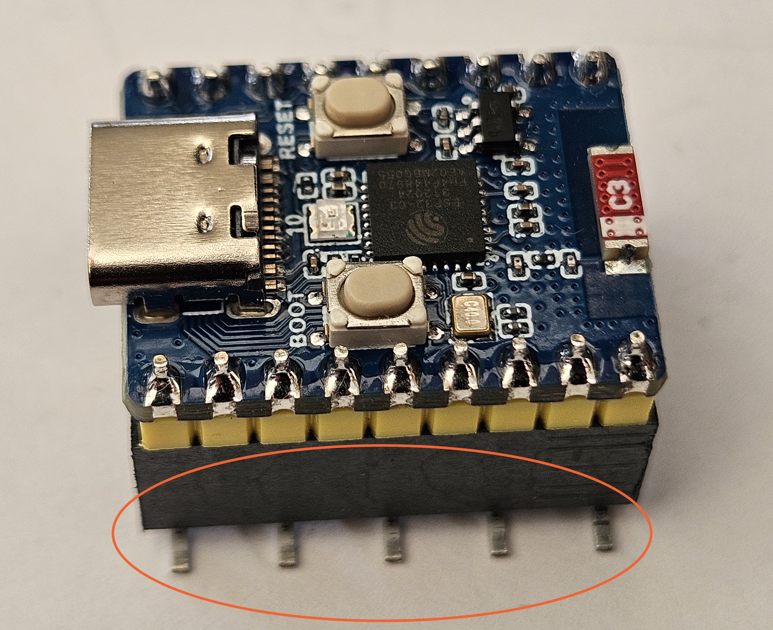
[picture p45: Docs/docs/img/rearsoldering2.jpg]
Hand solder


Both headers on the ESP32 module.
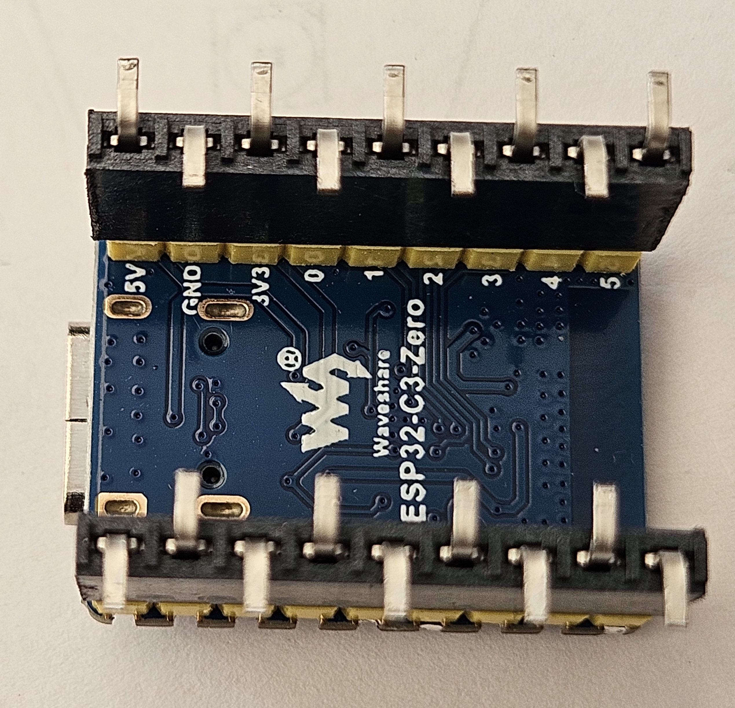
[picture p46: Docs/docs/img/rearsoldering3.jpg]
Hand solder


Place the assembly onto the pads, they should all line up. Press down on the ESP32 module to hold it in place. Place the soldering iron tip onto the metal contact and wait for it to heat up and melt the solder paste, repeat for all the pins on one side them turn the star around and repat for the second side.
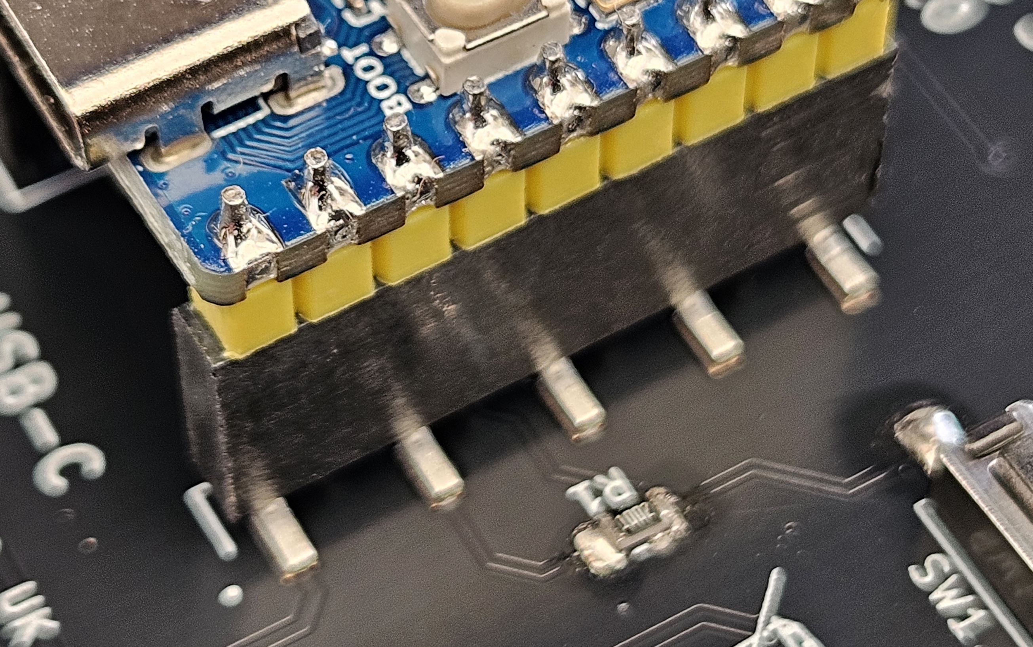
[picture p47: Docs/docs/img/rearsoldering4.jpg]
Hand solder


Carefully remove the ESP32 module, the headers will, if soldered correctly, remain on the PCB. Carefully solder the inside 8 pins, 4 on each side.
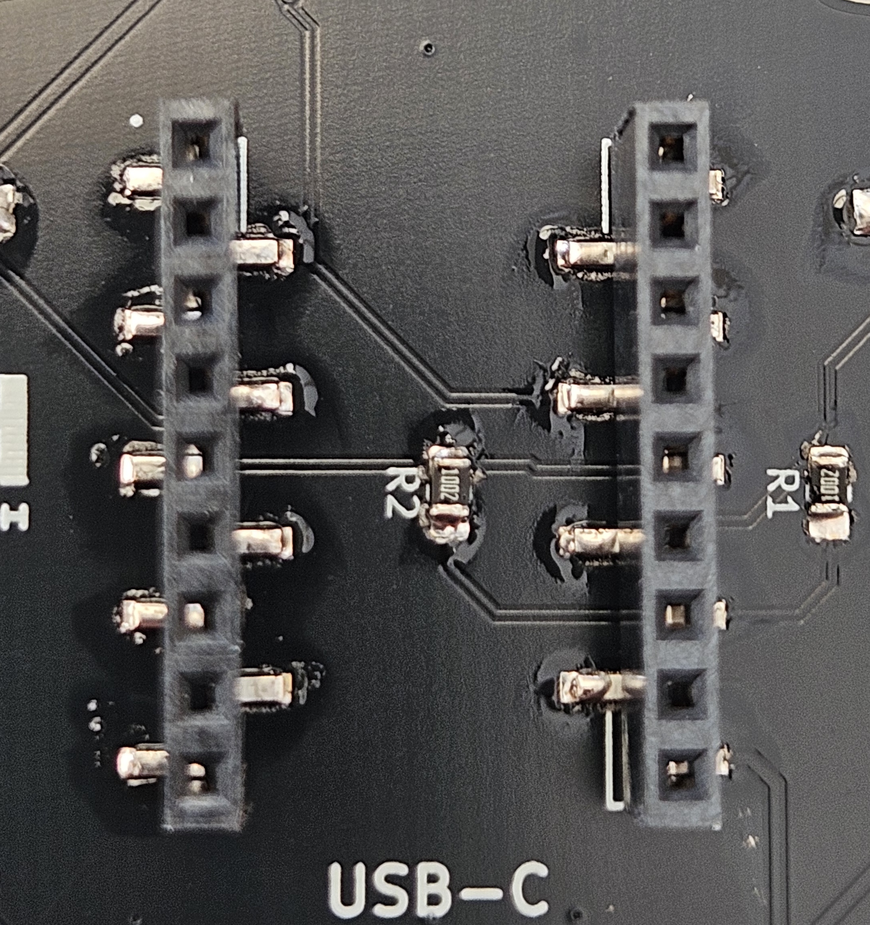
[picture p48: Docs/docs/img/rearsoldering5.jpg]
Hand solder


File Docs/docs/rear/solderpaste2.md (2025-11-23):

# Rear Solderpaste

The PCB is placed into the rear holder, the stencil is placed over the top and a scraper is used to spread the paste across the holes using a single smooth motion.

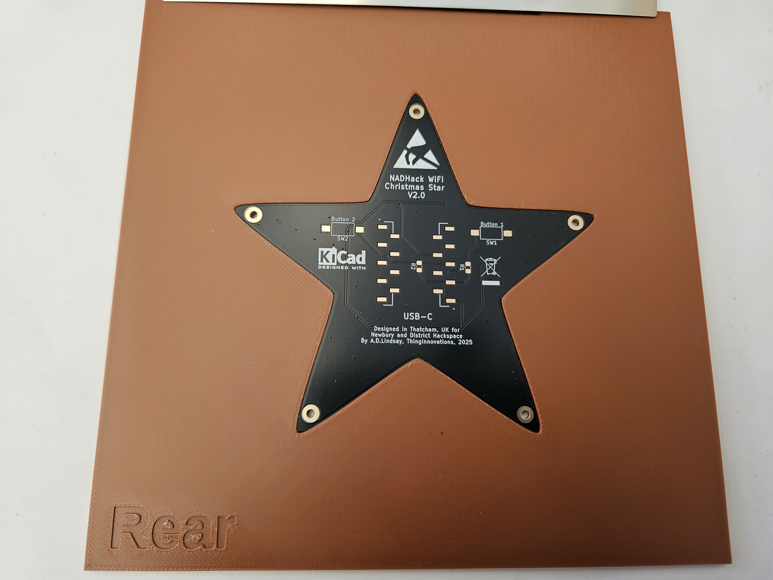
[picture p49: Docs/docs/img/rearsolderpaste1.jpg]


Apply stencil, ensure the pads are visible through the stencil holes. Apply the paste smoothly, ensuring the holes are filled.
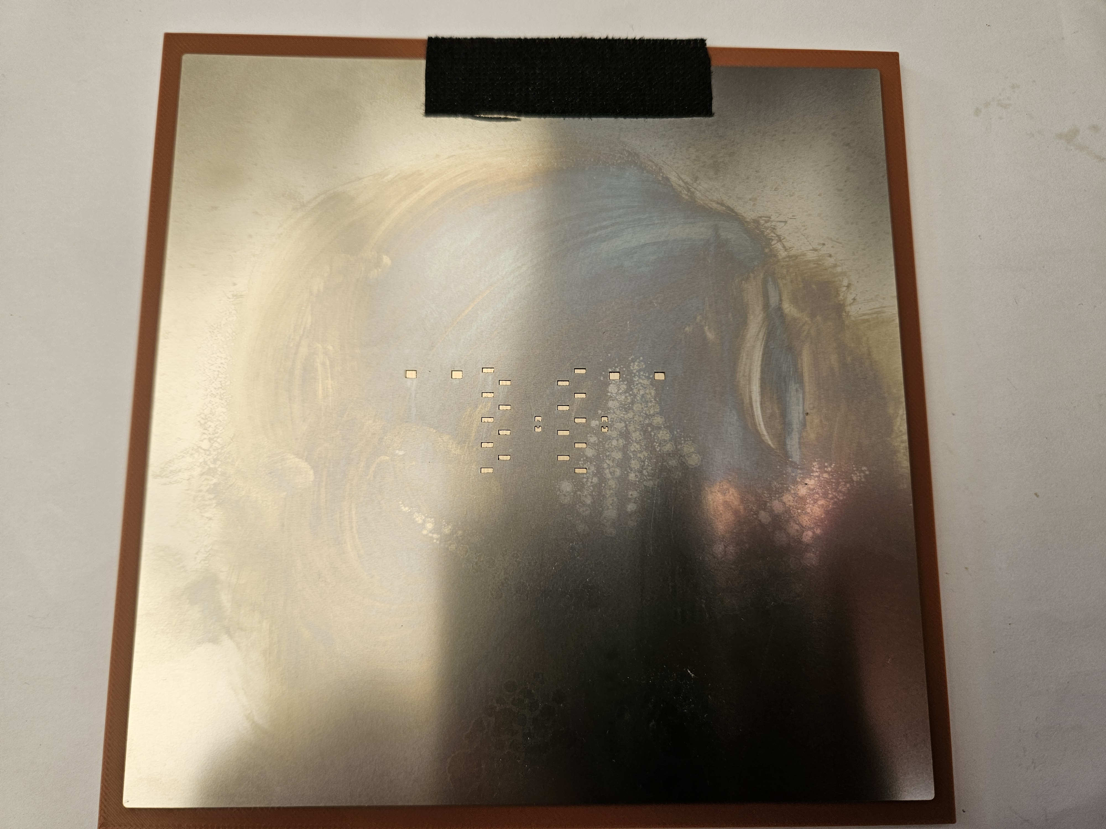
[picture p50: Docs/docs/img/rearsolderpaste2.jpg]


Carefully lift up the stencil and remove the PCB.
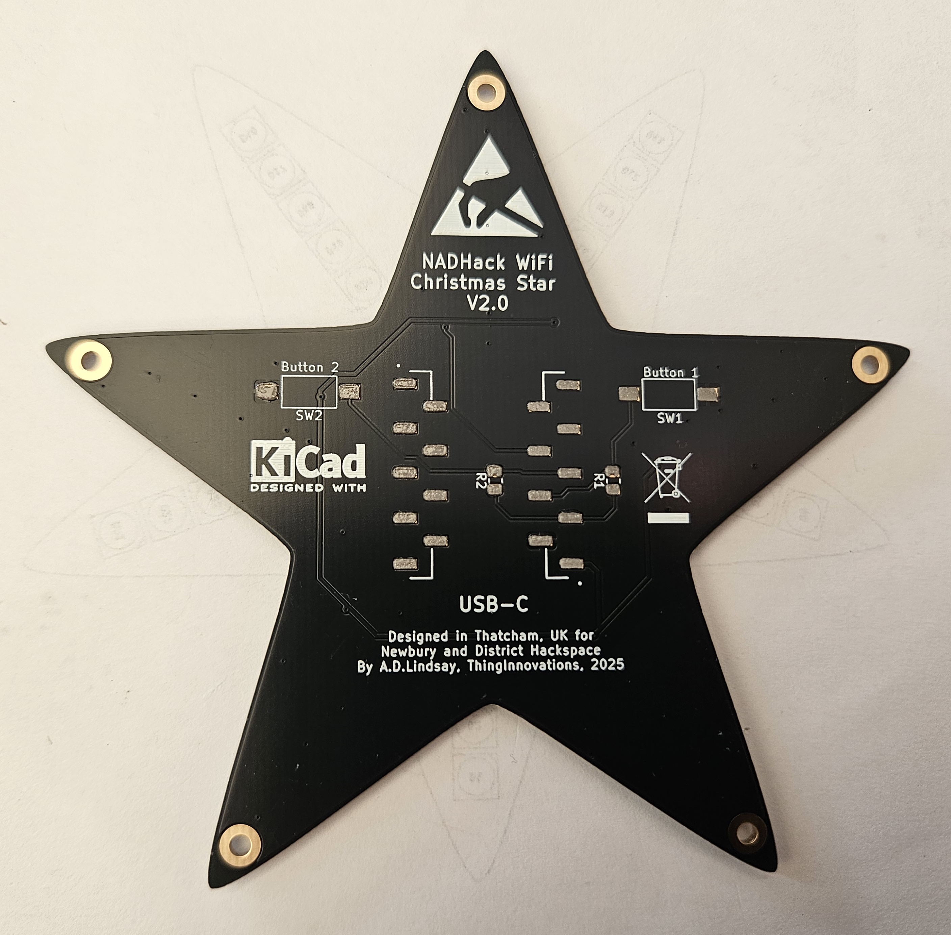
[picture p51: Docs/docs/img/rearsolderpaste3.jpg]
Paste


The board should look like this
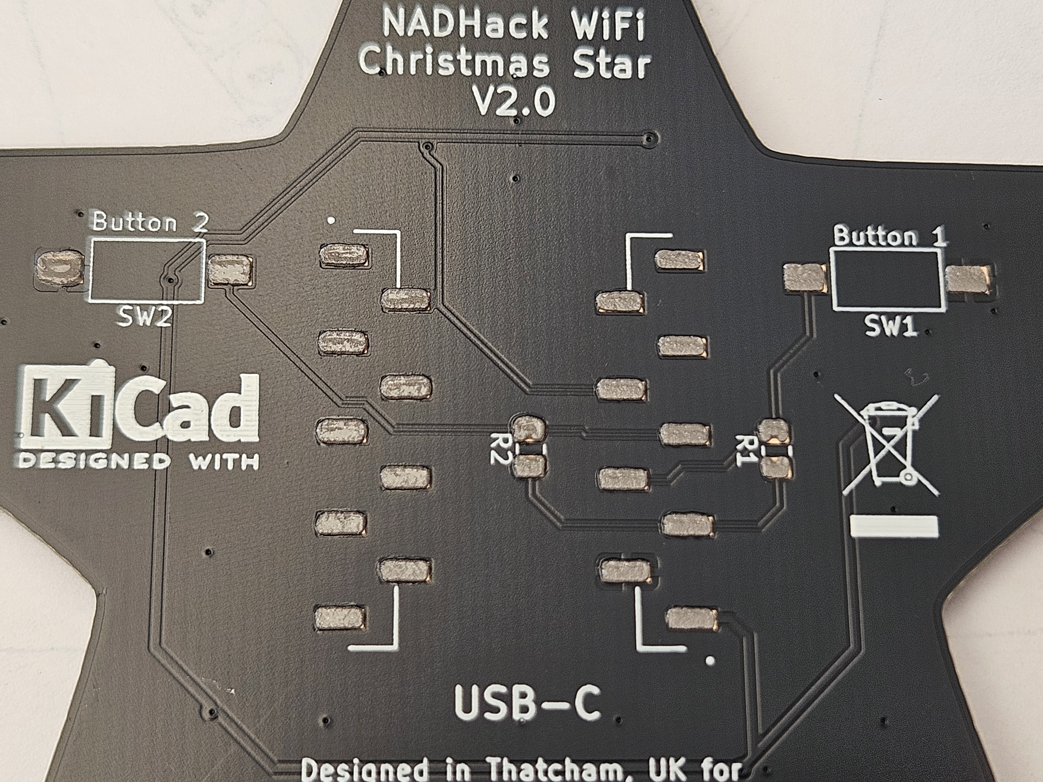
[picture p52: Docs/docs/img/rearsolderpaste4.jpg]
Paste


The stencil can be cleaned using IPA and a paper towel ready for the next person to use. Remember to clean both sides.

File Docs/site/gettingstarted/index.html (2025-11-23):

- Getting Started

# Getting Started

The Kit includes all the parts needed to build your star. kit

For easy of assembly, a custom made tray has been provided to hold the components except the strip of LEDs. Identify the components and place into the sections in the tray, the components in the strips can be removed. tools

Previous Next

Built with MkDocs (https://www.mkdocs.org/) using a theme (https://github.com/readthedocs/sphinx_rtd_theme) provided by Read the Docs (https://readthedocs.org).

« Previous Next »

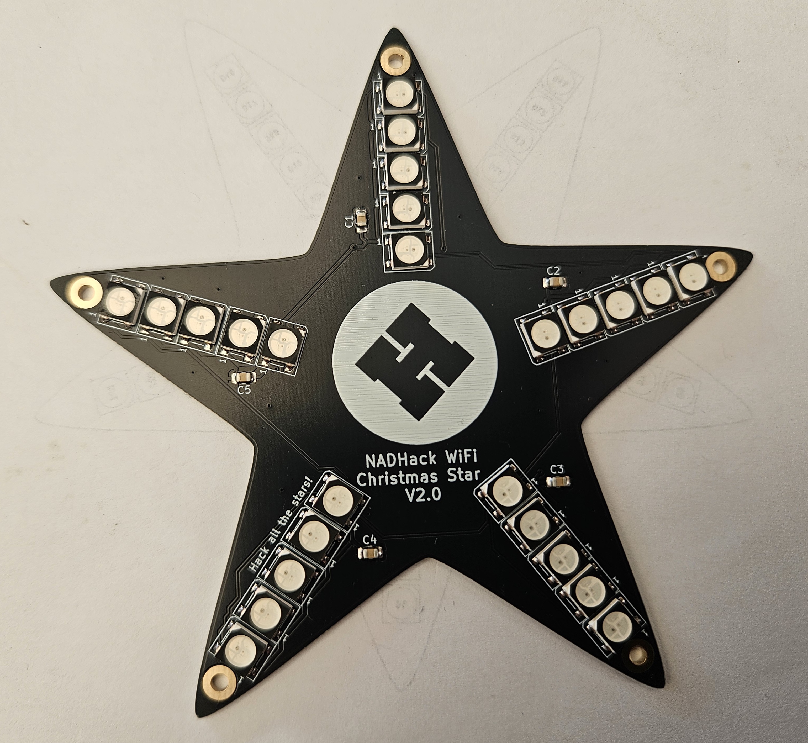
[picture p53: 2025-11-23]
Docs/site/img/frontsoldered.jpg

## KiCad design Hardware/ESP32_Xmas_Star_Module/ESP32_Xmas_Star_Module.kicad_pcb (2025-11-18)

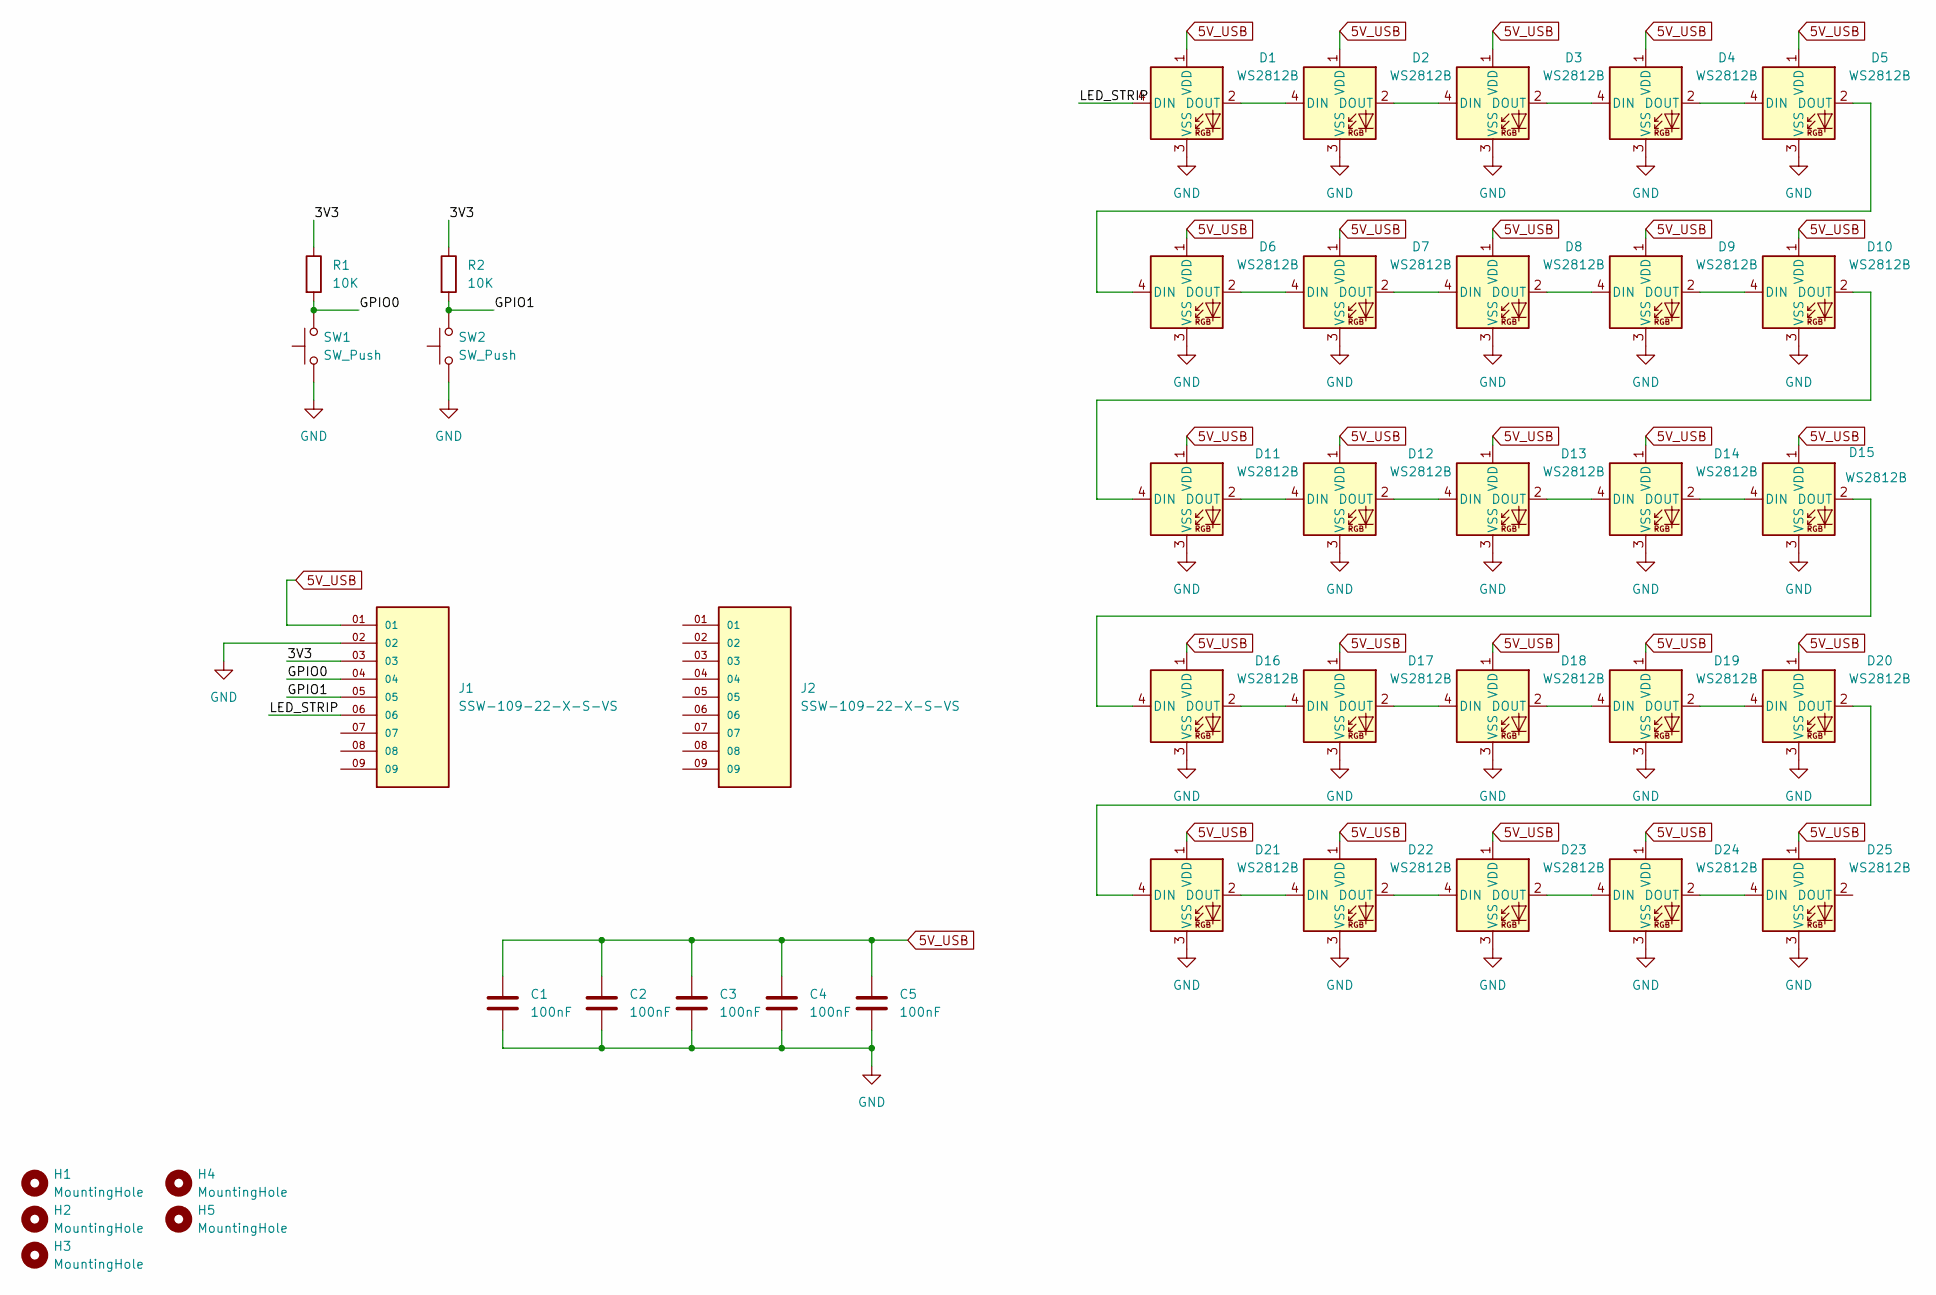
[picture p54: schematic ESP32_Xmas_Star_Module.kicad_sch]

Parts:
C1, C2, C3, C4, C5: 100nF; C_0805_2012Metric_Pad1.18x1.45mm_HandSolder
D1, D2, D3, D4, D5, D6, D7, D8, D9, D10, D11, D12, D13, D14, D15, D16, D17, D18, D19, D20, D21, D22, D23, D24, D25: WS2812B; LED_WS2812B_PLCC4_5.0x5.0mm_P3.2mm
H1, H2, H3, H4, H5: MountingHole; MountingHole_2.2mm_M2_Pad
J1, J2: SSW-109-22-X-S-VS; SAMTEC_SSW-109-22-X-S-VS; PARTREV B
R1, R2: 10K; R_0805_2012Metric_Pad1.20x1.40mm_HandSolder
SW1, SW2: SW_Push; SW_SPST_FSMSM

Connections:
5V_USB: C1.1, C2.1, C3.1, C4.1, C5.1, D1.1 (VDD), D2.1 (VDD), D3.1 (VDD), D4.1 (VDD), D5.1 (VDD), D6.1 (VDD), D7.1 (VDD), D8.1 (VDD), D9.1 (VDD), D10.1 (VDD), D11.1 (VDD), D12.1 (VDD), D13.1 (VDD), D14.1 (VDD), D15.1 (VDD), D16.1 (VDD), D17.1 (VDD), D18.1 (VDD), D19.1 (VDD), D20.1 (VDD), D21.1 (VDD), D22.1 (VDD), D23.1 (VDD), D24.1 (VDD), D25.1 (VDD), J1.01
/3V3: J1.03, R1.1, R2.1
/GPIO0: J1.04, R1.2, SW1.2
/GPIO1: J1.05, R2.2, SW2.2
/LED_STRIP: D1.4 (DIN), J1.06
GND: C1.2, C2.2, C3.2, C4.2, C5.2, D1.3 (VSS), D2.3 (VSS), D3.3 (VSS), D4.3 (VSS), D5.3 (VSS), D6.3 (VSS), D7.3 (VSS), D8.3 (VSS), D9.3 (VSS), D10.3 (VSS), D11.3 (VSS), D12.3 (VSS), D13.3 (VSS), D14.3 (VSS), D15.3 (VSS), D16.3 (VSS), D17.3 (VSS), D18.3 (VSS), D19.3 (VSS), D20.3 (VSS), D21.3 (VSS), D22.3 (VSS), D23.3 (VSS), D24.3 (VSS), D25.3 (VSS), J1.02, SW1.1, SW2.1
unnamed: D1.2 (DOUT), D2.4 (DIN)
unnamed: D2.2 (DOUT), D3.4 (DIN)
unnamed: D3.2 (DOUT), D4.4 (DIN)
unnamed: D4.2 (DOUT), D5.4 (DIN)
unnamed: D5.2 (DOUT), D6.4 (DIN)
unnamed: D6.2 (DOUT), D7.4 (DIN)
unnamed: D7.2 (DOUT), D8.4 (DIN)
unnamed: D8.2 (DOUT), D9.4 (DIN)
unnamed: D9.2 (DOUT), D10.4 (DIN)
unnamed: D10.2 (DOUT), D11.4 (DIN)
unnamed: D11.2 (DOUT), D12.4 (DIN)
unnamed: D12.2 (DOUT), D13.4 (DIN)
unnamed: D13.2 (DOUT), D14.4 (DIN)
unnamed: D14.2 (DOUT), D15.4 (DIN)
unnamed: D15.2 (DOUT), D16.4 (DIN)
unnamed: D16.2 (DOUT), D17.4 (DIN)
unnamed: D17.2 (DOUT), D18.4 (DIN)
unnamed: D18.2 (DOUT), D19.4 (DIN)
unnamed: D19.2 (DOUT), D20.4 (DIN)
unnamed: D20.2 (DOUT), D21.4 (DIN)
unnamed: D21.2 (DOUT), D22.4 (DIN)
unnamed: D22.2 (DOUT), D23.4 (DIN)
unnamed: D23.2 (DOUT), D24.4 (DIN)
unnamed: D24.2 (DOUT), D25.4 (DIN)

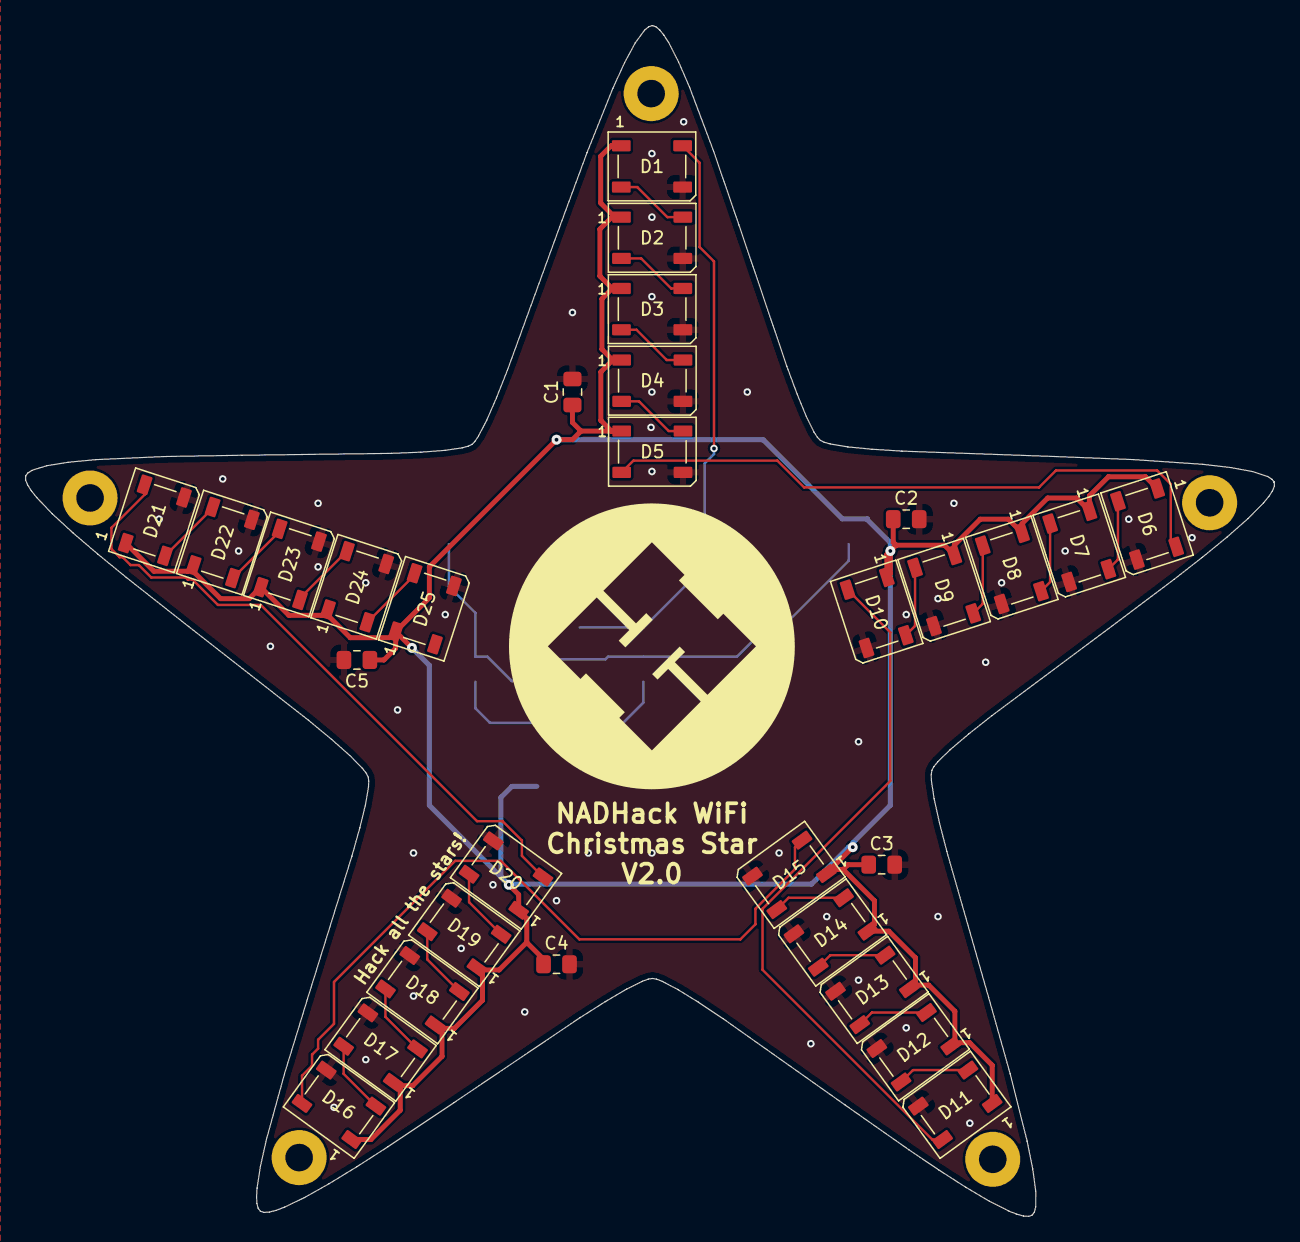
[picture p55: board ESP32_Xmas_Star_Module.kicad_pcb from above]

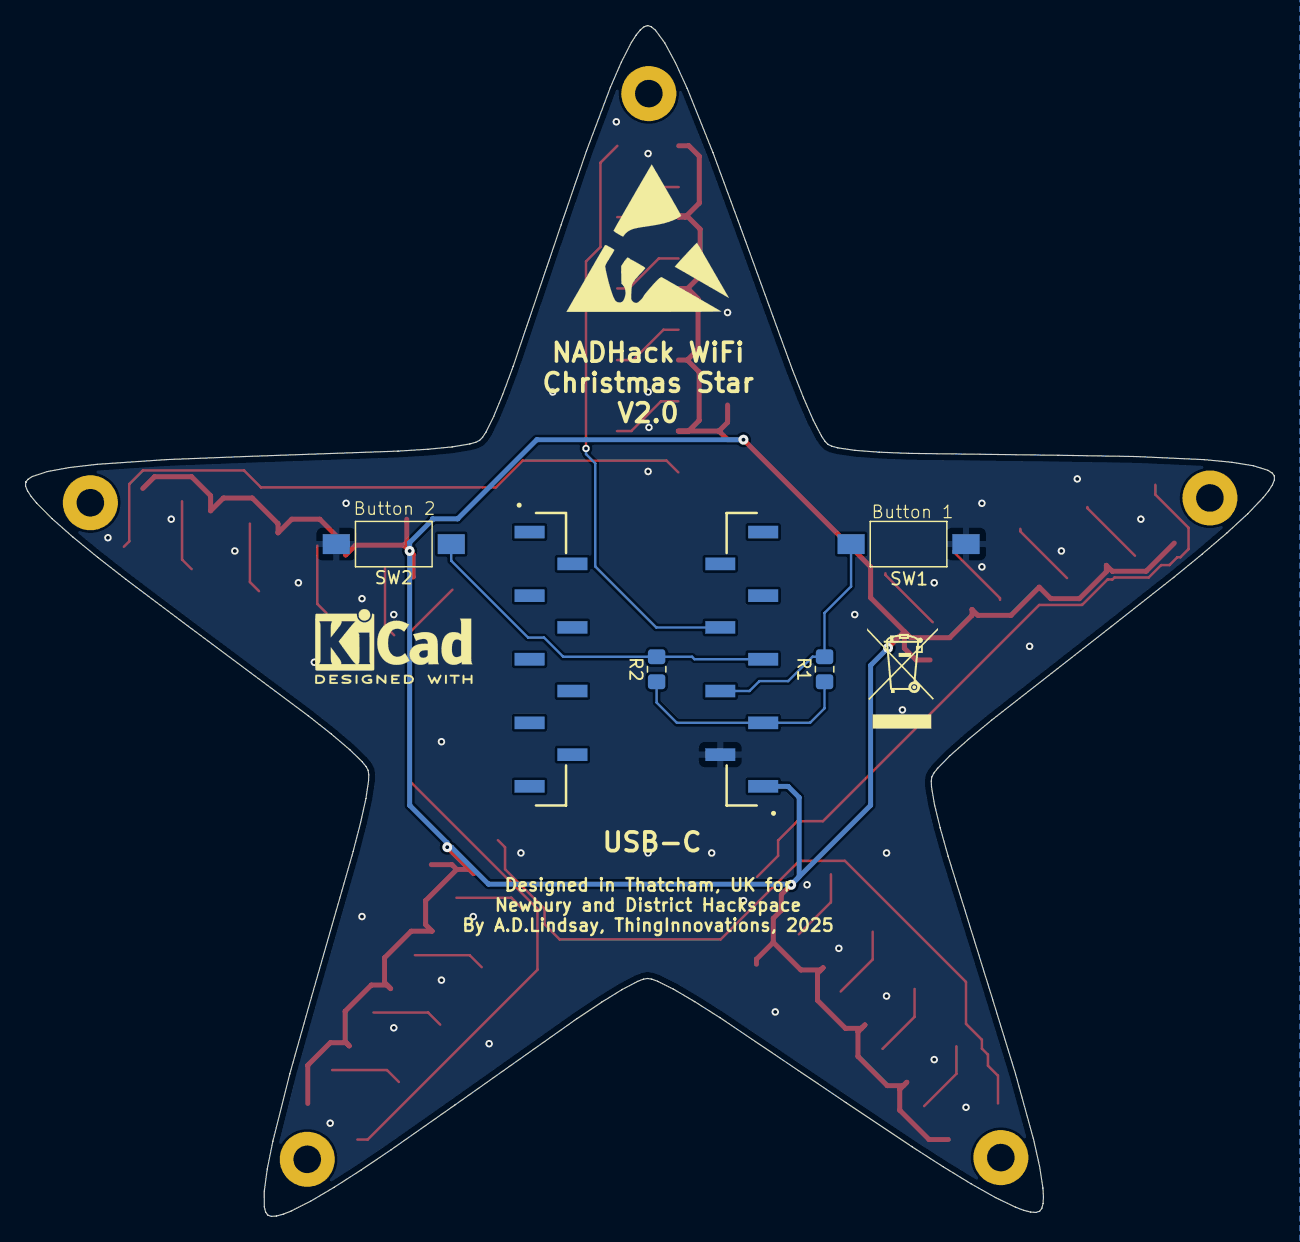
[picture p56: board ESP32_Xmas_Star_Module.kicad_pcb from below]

Board: 2 copper layers, 99.8 x 95.1 mm, 41 parts (6 on the bottom side), 30 nets.

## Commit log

2025-11-18 ESP32 based Xmas Star
    Version 2.0 using SMD LED
    [BOM_ESP32_Xmas_Star_Module.xlsx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]
2025-11-23 Added documentation and addons
    [BOM_ESP32_Xmas_Star_Module.xlsx, StarCover.scad, StarCover.stl]
2025-11-29 Tree topper adapter
    Use the star as a topper for your Christmas tree
    [StarBracket.scad, StarBracket.stl]
2025-11-30 Assembly guide updates
2025-12-09 Added starstick
    [seasonal_star_stick_v3.3mf, seasonal_star_stick_v3.stl]
2025-12-09 Added fusion360 file
    [Seasonal_Star.3mf, Seasonal_Star.f3d, Seasonal_Star.stl]
